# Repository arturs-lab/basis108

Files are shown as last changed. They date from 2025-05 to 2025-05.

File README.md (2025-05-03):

# basis108
Document my computer Basis 108 and its components. Organize various bits of documentation from 3rd parties that I've found across the web.

It is not my intent to violate any rights of Copyright/Trade Mark owners here. If any lawful rights owner finds content here which they do not wish included here, please contact me and I will promptly remove such content.

# History
I bought my Basis 108 in Netherlands around 1990. It appears to be a kit or early version of this computer as compared to production version that I've found traces of out on the internet. My copy came enclosed in home made case made of stainless steel with main board mounted on wooden straps glued to it. Floppy drives were mounted using metal straps resembling those found in kid's construction kits. main boards itself has no silkscreen but appears to have been produced and assembled in factory. A separate keyboard was included which was controlled by its own processor and sent keystrokes to the computer over a parallel flat ribbon cable. Sadly, this keyboard was lost.

# Platform
This computer appears to be a clone of Apple ][ with Z80 processor integrated into the main board. This allowed it to not only run Apple DOS but also CP/M. I have disks with CP/M 2.2 and 3.0. I spent most of my time in the latter writing programs in Turbo Pascal 3.0 and Z80 assembly. Besides the main board and floppy drives, the machine came with a built in power supply delivering +12, +5, -5 and -12V. I no longer have this power supply and use PC power supply instead. It also came with a Floppy Drive Controller. This controller appears to have two connectors for a typical Apple format Floppy drives. It also has some additional circuitry and what appears to be a Shugart style interface which is connected to two Teac FD-55F-03-U drives. These drives appear to have been modified to allow 80 or 40 track operation controlled by a switch mounted on front panel of computer.

# Please help!
If anyone out there has more information about this computer, please reach out to me and share what you have so that I may 8nclude it in this archive.

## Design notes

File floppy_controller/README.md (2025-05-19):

This appears to be a version of Ehring FDC4 controller.

The Ehring FDC4 is described here
https://www.applefritter.com/appleii-box/H085_AppleIIFDC4.htm

# Controller modifications

Originally the only modification was that switch 1 on switch block was turned on, and two wires wewre soldered across it which go to a switch mounted on front panel. This allows switching both drives between 80 and 40 track mode by double-stepping track motor in 40 track mode.

Second modification was adding two pullup resistors pulling up unused INDEX and DRIVE CHANGE lines. Both these signals come our of floppy drives through open collector output which means that no signal will show on them without a pullup. This comes in handy when monitoring the system with oscilloscope and has no other affect since these lines are otherwise unused.
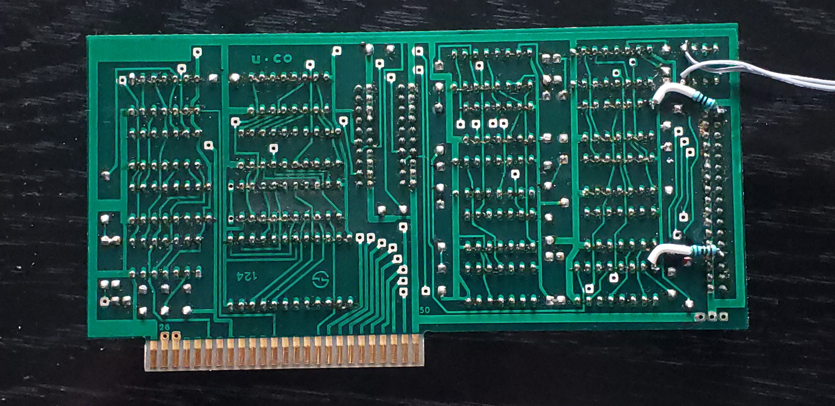
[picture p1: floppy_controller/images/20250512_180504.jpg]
Both mods seen here


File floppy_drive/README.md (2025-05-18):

The black/white wire soldered to where R14 used to be as seen here
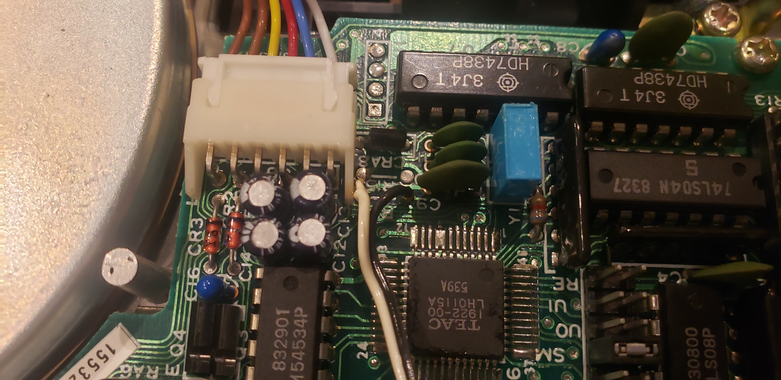
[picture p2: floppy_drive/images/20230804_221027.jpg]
bw cable

goes to a switch with that resistor soldered to it.
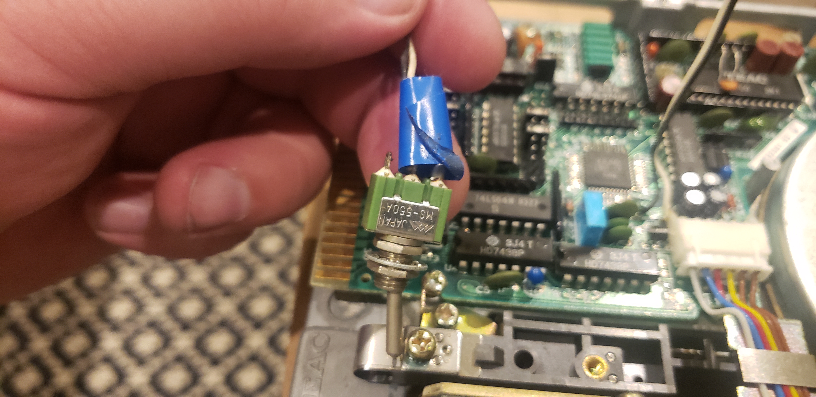
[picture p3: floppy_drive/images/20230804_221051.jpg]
switch

This allows switching the drive between 80 and 40 track mode.

Both drives have this modification on them. There also is a switch connected to floppy drive controller which switches both drives between single-sided and double-sided modes.

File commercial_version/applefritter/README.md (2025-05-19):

This is some information found at applefritter bulletin board talking about clone of Basis 108, which itself is a clone of Apple ][.

Since Bulletin Boards come and go, I've saved the content of this post to Basis 108 Clone _ Applefritter.htm

* https://www.applefritter.com/content/basis-108-clone
* https://archive.org/details/basis108SurvivalPack
* http://s180250204.onlinehome.us/Basis/Basis-108-EPROMs.zip
* http://oldcomputer.info/keep/c/museum/8bit/Basis_108

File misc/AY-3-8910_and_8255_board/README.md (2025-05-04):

Board that I built. It interfaces AY-3-8910 PSG and Intel 8255 PIO chip to Basis108. I also added some other experimental circuitry like IDE interface.

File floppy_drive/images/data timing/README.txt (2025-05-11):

I could not capture any pulses on READY or INDEX lines. The drive does have an index sensor but apparently it's been disabled.

On DATA line, 3 types of pulses during data transfer:
all pulses 1us wide
4us apart
7.5us apart
11.5us apart - this may be some sort of separator

Index pulses are present on index photodiode, but not on pin 8 of cable which is constantly low. They do appear on pin 8 once it gets pulled up to 5V through a 1K resistor. This suggests that the controller does not use index pulses.

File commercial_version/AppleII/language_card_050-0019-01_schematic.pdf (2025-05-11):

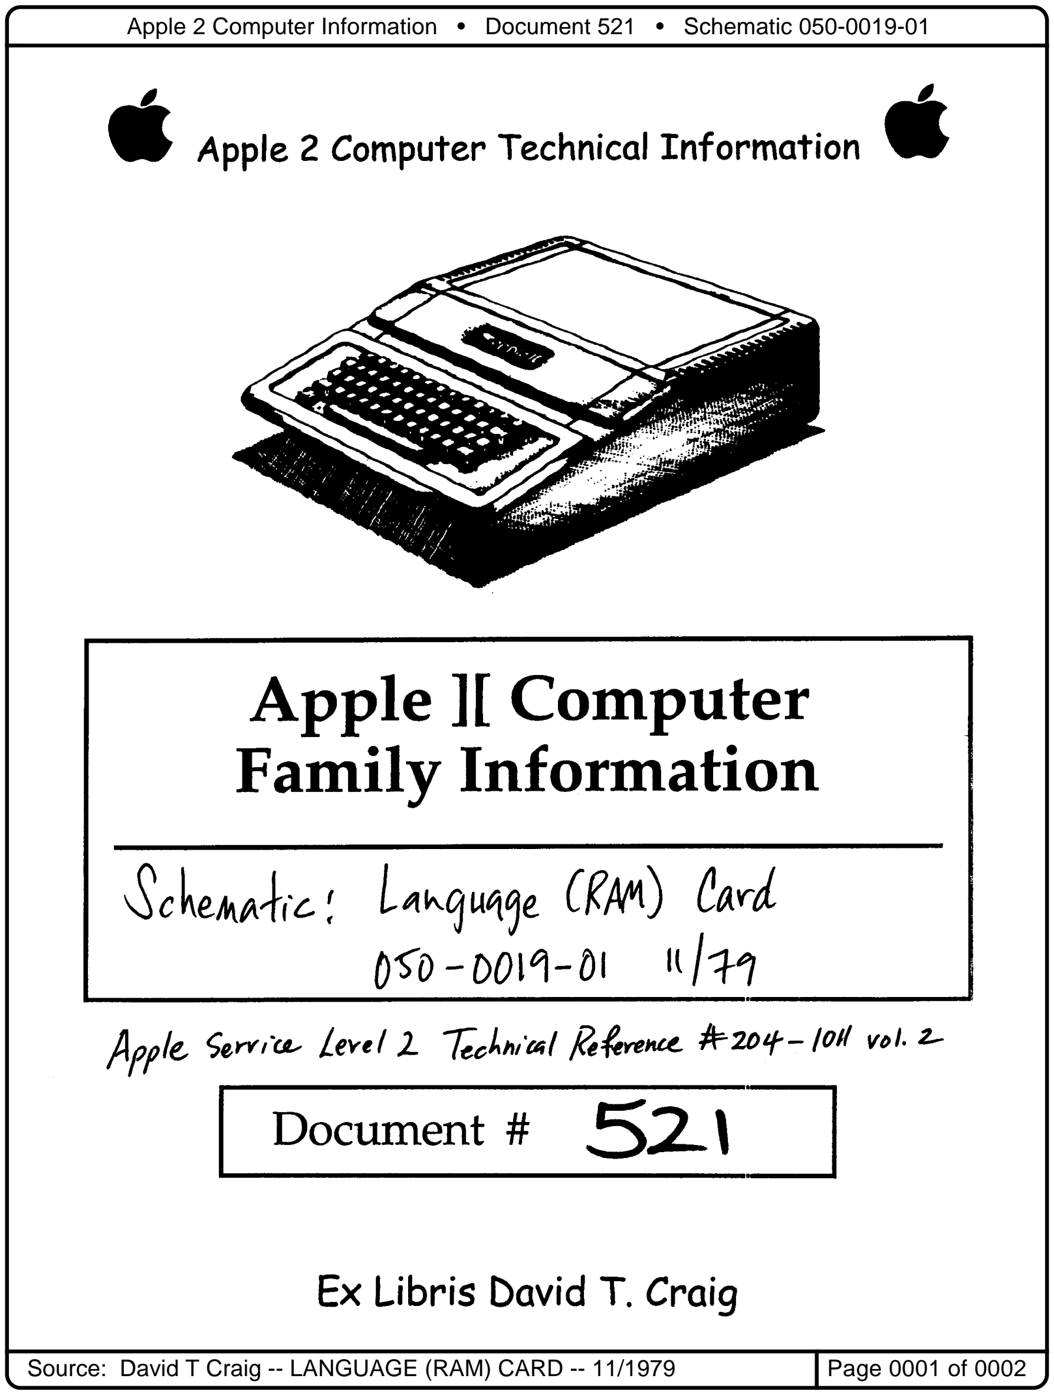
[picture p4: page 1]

Apple 2 Computer Information • Document 521 • Schematic 050-0019-01

Source: David T Craig -- LANGUAGE (RAM) CARD -- 11/1979 | Page 0001 of 0002

Apple 2 Computer Information • Document 521 • Schematic 050-0019-01

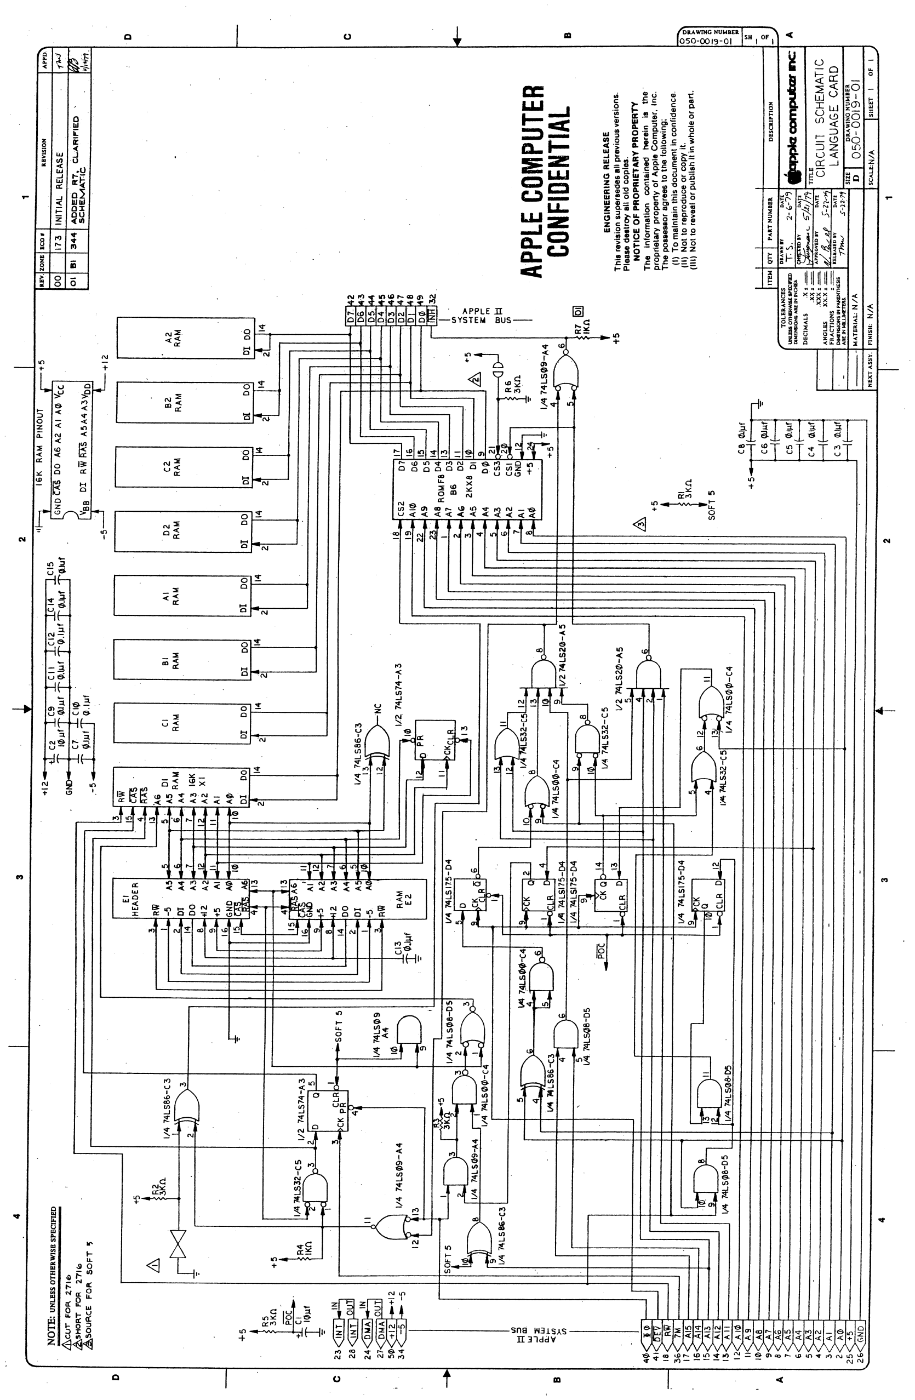
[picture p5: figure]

Source: David T Craig -- LANGUAGE (RAM) CARD -- 11/1979 | Page 0002 of 0002

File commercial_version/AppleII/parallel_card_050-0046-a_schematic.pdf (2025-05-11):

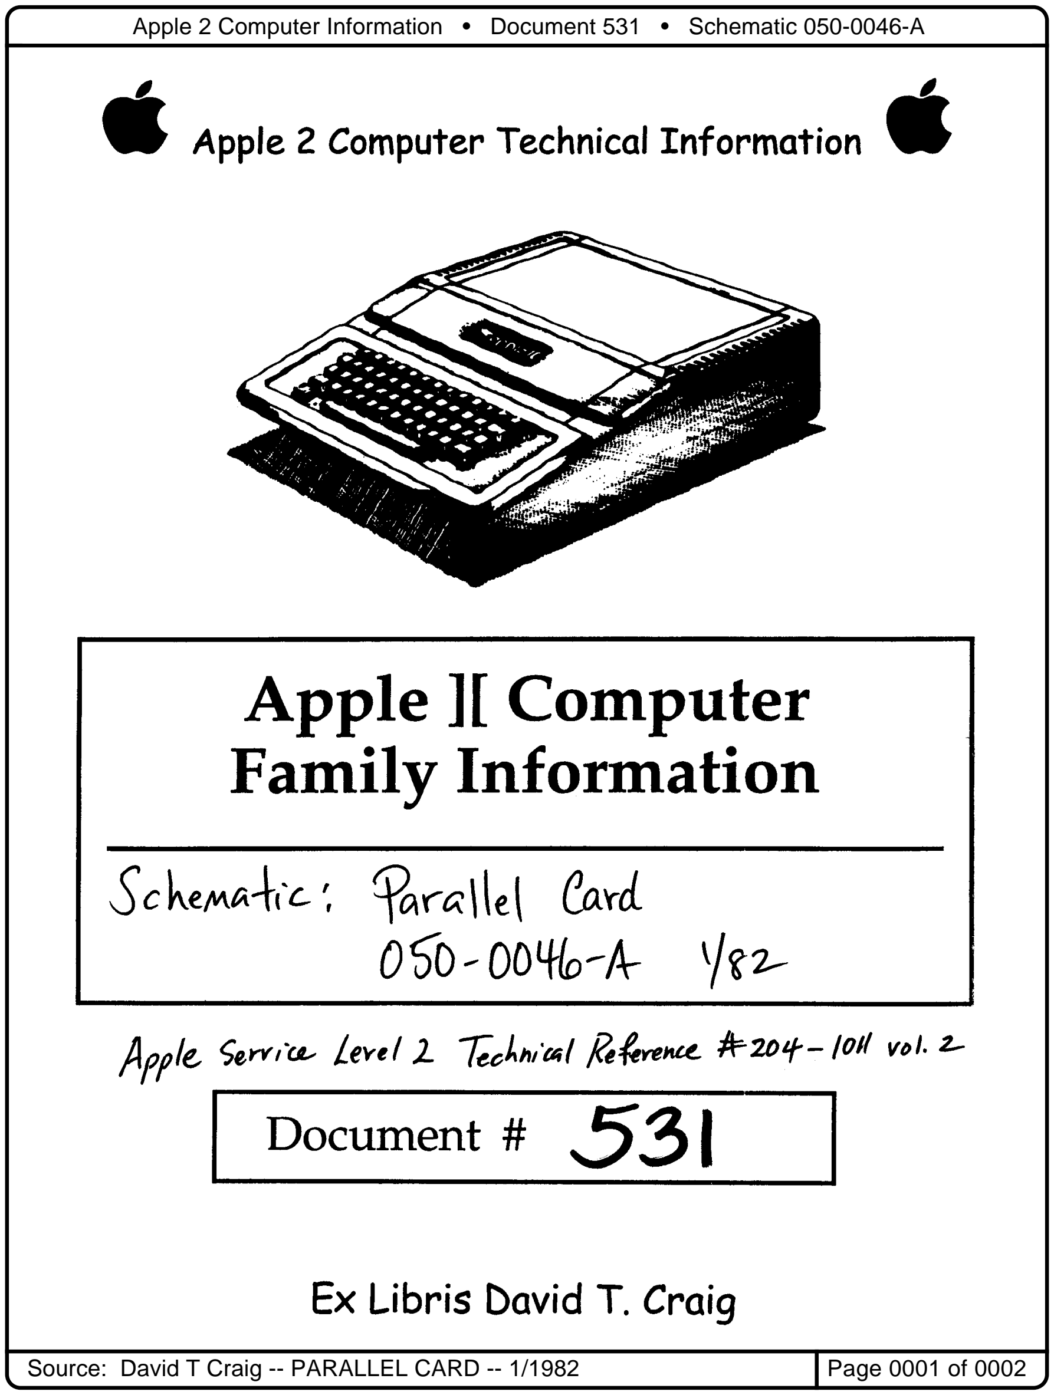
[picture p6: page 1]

Apple 2 Computer Information • Document 531 • Schematic 050-0046-A

Source: David T Craig -- PARALLEL CARD -- 1/1982 | Page 0001 of 0002

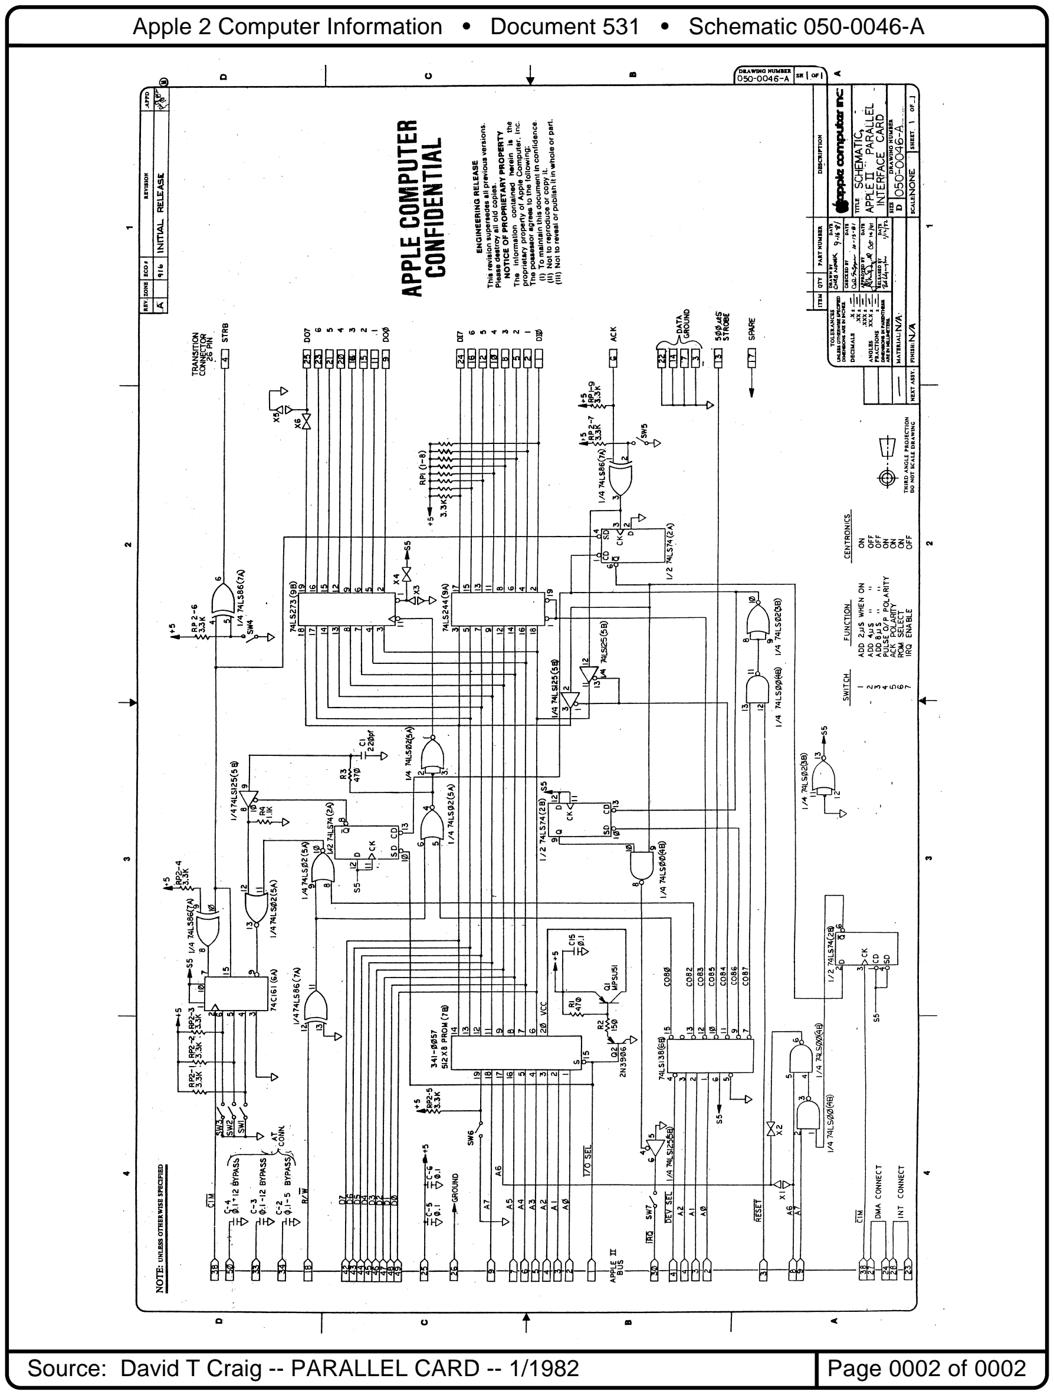
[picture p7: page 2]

Apple 2 Computer Information • Document 531 • Schematic 050-0046-A

Source: David T Craig -- PARALLEL CARD -- 1/1982 | Page 0002 of 0002

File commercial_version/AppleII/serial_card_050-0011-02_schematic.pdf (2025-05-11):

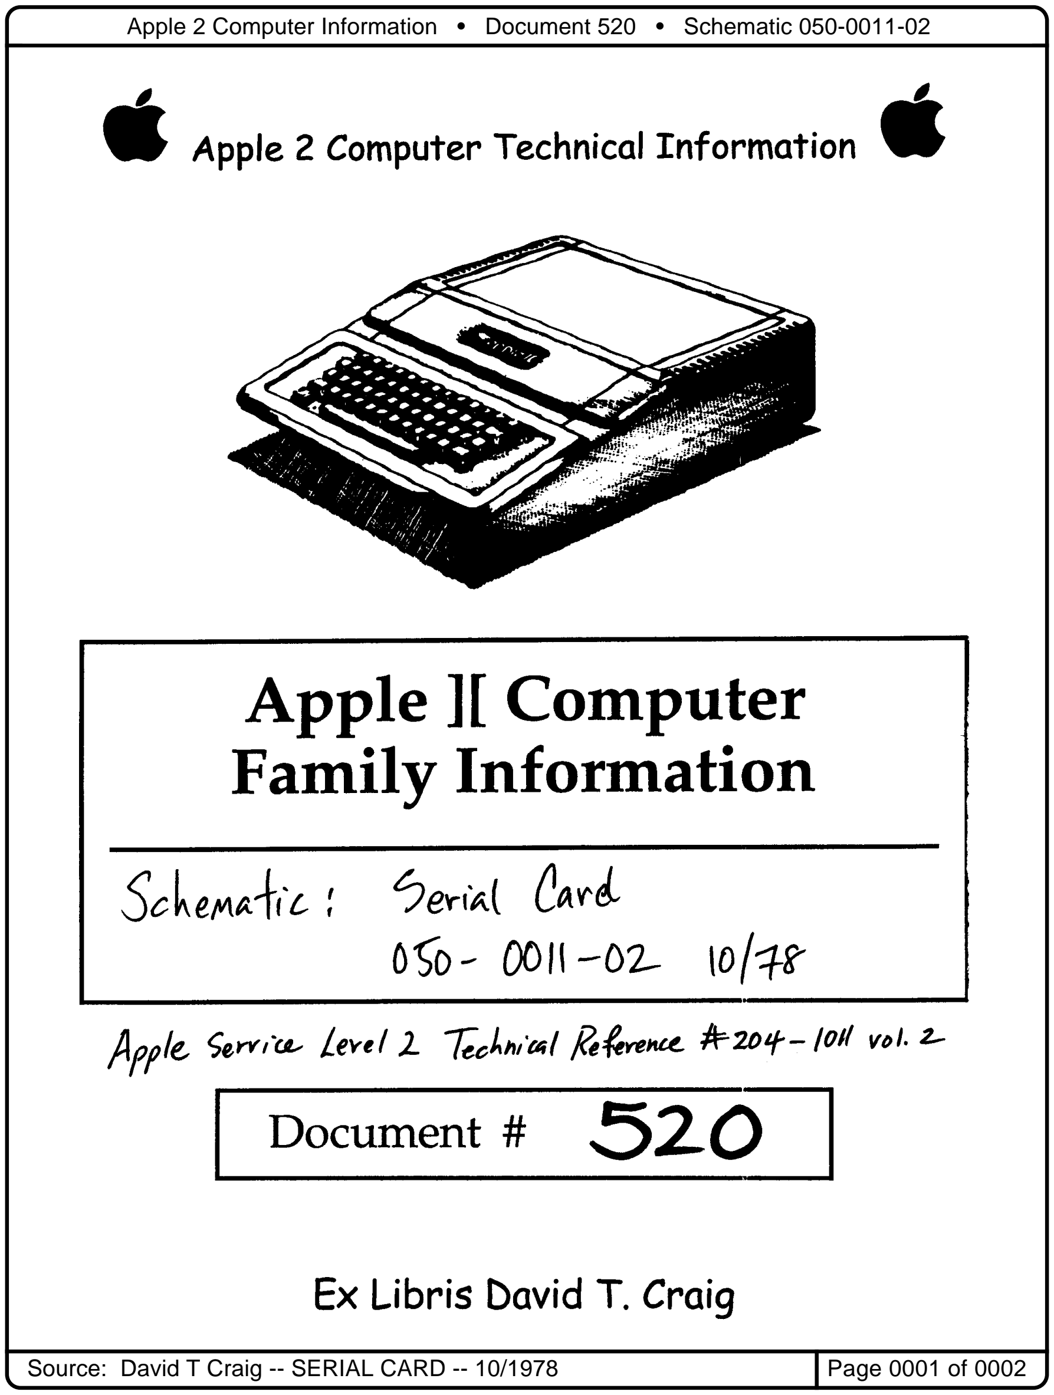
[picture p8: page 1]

Apple 2 Computer Information • Document 520 • Schematic 050-0011-02

Source: David T Craig -- SERIAL CARD -- 10/1978 | Page 0001 of 0002

Apple 2 Computer Information • Document 520 • Schematic 050-0011-02

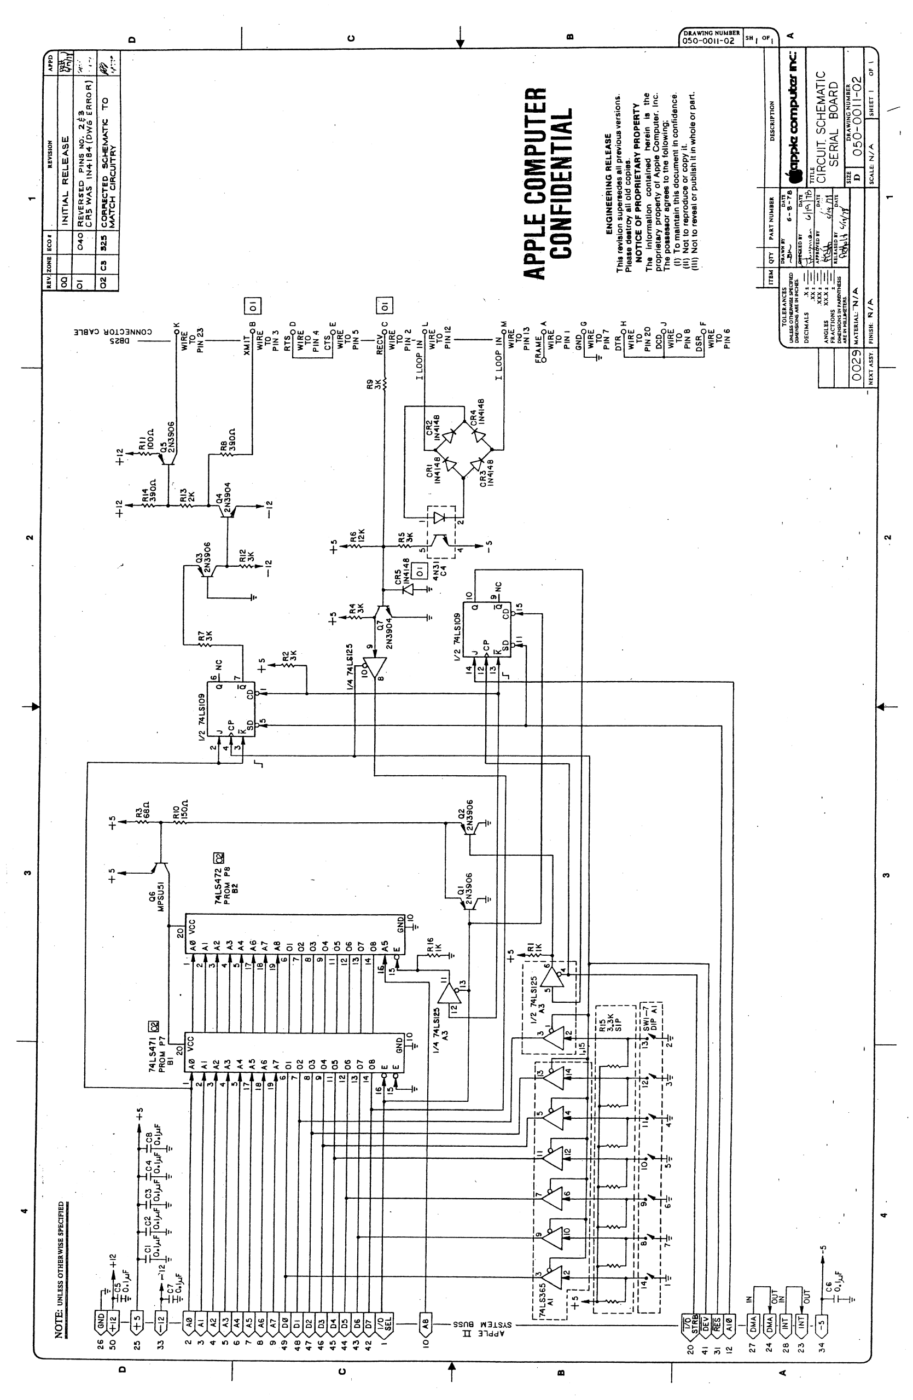
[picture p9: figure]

Source: David T Craig -- SERIAL CARD -- 10/1978 | Page 0002 of 0002

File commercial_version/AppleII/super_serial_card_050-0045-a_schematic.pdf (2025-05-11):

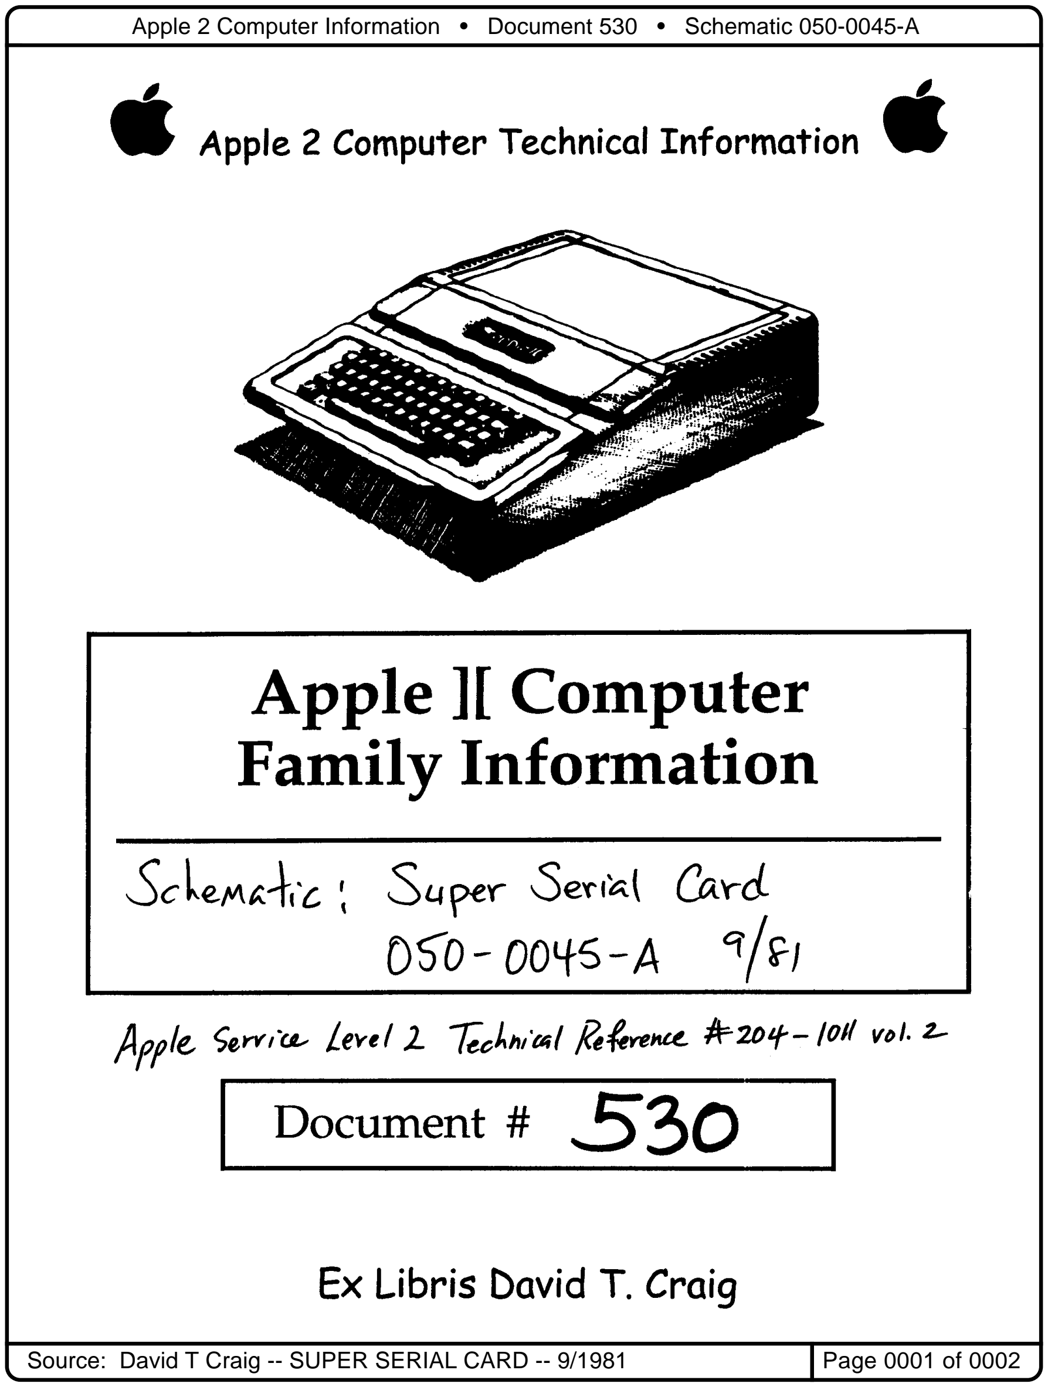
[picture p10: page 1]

Apple 2 Computer Information • Document 530 • Schematic 050-0045-A

Source: David T Craig -- SUPER SERIAL CARD -- 9/1981 | Page 0001 of 0002

Apple 2 Computer Information • Document 530 • Schematic 050-0045-A

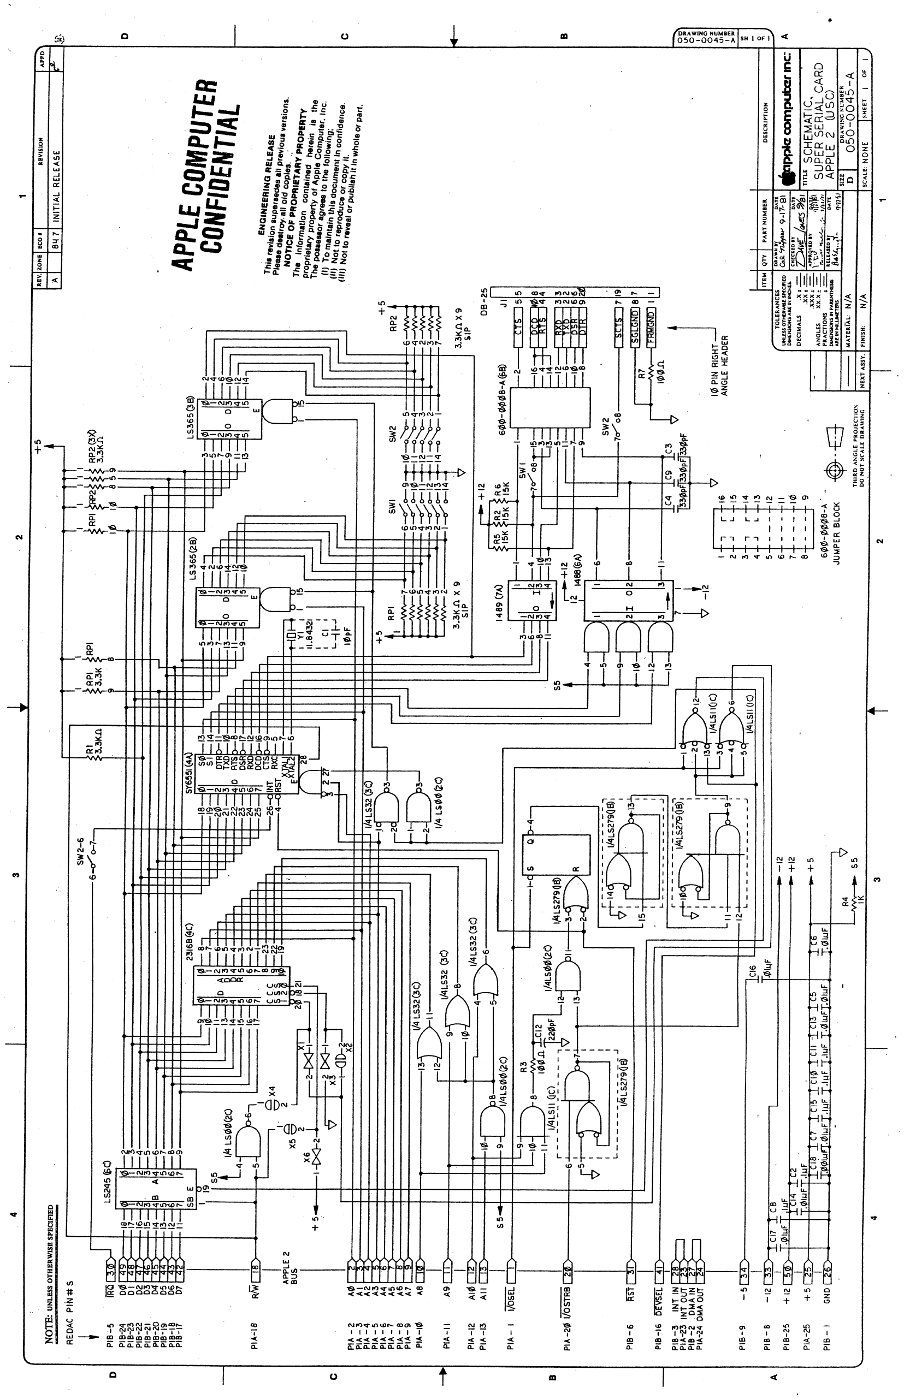
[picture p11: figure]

Source: David T Craig -- SUPER SERIAL CARD -- 9/1981 | Page 0002 of 0002

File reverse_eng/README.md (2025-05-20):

# Disassembly of code
Reverse engineering code from Basis 108 ROMs and CPM floppies to understand CPM boot process

Boot sectors from CP/M disk tracks 0 - 2 get loaded into memory starting at $800, then code gets executed starting from $801

# Data corruption analysis

I shared my thoughts on possible EPROM data corruption in my comments in README.md file in main_board/rom directory.

Focusing on d5 chip:
As seen in MD5 checksums, images of d5 EPROM differ across the three copies available
```
bcaa84a76a547e1f8acba9525073f068  d5.bin
cfe2c4aa8eed8fe9955d166b73957061  d5_label_2024.bin
45e97c54fc85d5095fced5f40a284ec6  d5_label_2025.bin
```
* The values that differ between the three copies are the smallest in d5.bin and bigger
 in one or both the other two copies which are more recent. This is true for both halves of EPROMs.
* The value in "middle" d5_label_2024.bin sometimes equals to that in d5.bin, sometimes
 to d5_label_2025.bin. But values in more recent file are never smaller than in an older file.
* Initially I thught that the content of two halves of d5 EPROM contain two different
 versions of the code. However both halves showing the same kind of differences as described
 above leads me to believe that the code is the same, it just aged differently.

To try to restore this chip to original values I did the following:
* I created a script make_single_byte_hex.bash which splits each available file in two halves and generates a file with one hex value per line.
* Then I wrote a python script which takes various combinations of these files and compares values in them. This allowed me to observe that values in the files only grow with time, never shrank.
* Using the same python file I can compare the two halves of the oldest file I have and use the smaller value of the two in the output. This hopefully restores the correct value for the given location. Unless they both got corrupted differently and neither is correct.
* This script also can output data in Intel hex format which will fill one half of 2764 EPROM. I saved this output to file d5_restore.hex. I then used Xgecu software to load this file twice to fill entire chip and output resulting file as d5_restore_x2.hex.
Sadly none of this work was of much use. I ended up with a, EPROM which didn't work. Meanwhile the original EPROM with all of its discrepancies, when put back in machine - works fine. Perhaps all the past readings of it are incorrect. Still, I'm documenting all this work in case it becomes handy in the future.

What puzzles me is that the machine seems to still be operating correctly despite this seemingly deep corruption. Either the EPROM is fine or I'm not hitting the locations that are corrupted or the corruption is not enough to result in crash. Although it may be enough to lead to data corruption on disks for example. I wonder if corruption only affects the EPROM memory locations that are never accessed because I'm not using this part of code. And the locations that are accessed get sort of "refreshed" enough to keep them alive.

## Notes
* 6502 reset/NMI vectors
```
$fffa	faaa	; NMI
$fffc	fa62	; reset
$fffe	fa40	; IRQ/BRK
```
## manual page 56
```
3f0,3f1	BRK handler vector
3f2,3f2	warm start vector ( monitor Q uses this vector)
3f3		einshalt byte
3f5,6,7	jump command for fpbasic subroutine. normally 4c 58 ff
3f8,9,a	jump command for USER (U) call
3fb,c,d	jump to NMI handler
3fe,3ff	INT handler vector
4f9	     0=40 char !=0 = 80 char
```
## memory banks page 58

| Bank 0 active | Bank 1 active | Adress space |
|---|---|---|
|  $C060w |  $C061w |  $0000 $1FFF |
|  $C062w |  $C063w |  $2000 $3FFF |
|  $C064w |  $C065w |  $4000 $5FFF |
|  $C066w |  $C067w |  $6000 $7FFF |
|  $C068w |  $C069w |  $8000 S9FFF |
|  $C06Aw |  $C06Bw |  $A000 $BFFF |
|  $C06Cw |  $C06Dw |  $D000 $DFFF |
|  $CO6Ew |  $CO6Fw |  $E000 $FFFF |

## The static RAM for the 80 column display
```
$C00Dw Additional RAM switched on, normal RAM switched off
$C00Cw Additional RAM switched off, Normal RAM switched on
```
## io ports page 97

## z80 part page 99
### Controlling the Z-80 Section
The Z-80 section is controlled by write commands to the memory space, which normally contains
peripheral ROMs. It is very important to work with write commands to ensure that the 6502 
does not perform two accesses in a row (this would prevent switching back to the 6502).
When the BASIS 108 is turned on, the (RESET) signal turns off the Z-80 section.
The (RESET) signal is synchronized with the internal clock to ensure that a write operation 
cannot be interrupted. The Z-80 immediately enters a wait mode and remains there until 
the Z-80 section is activated.

After receiving a write command in the correct memory area, the Z-80 section is turned on. 
The Z-80 remains in a wait mode until a memory clock with address information for the 
Z-80 section appears. The Z-80 is now released from wait mode and runs without further wait cycles.
Upon receipt of another write command in the same memory area (this time from the Z-80 itself), 
the Z-80 is shut down. The memory addresses for controlling the Z-80 are:
`$C100 - $C1FF`

## Mapping of Z80 address space to 6502 address space
| Z-80 Adresses	| 6502 Adresses |
|---|---|
|  $0000-$0FFF  |  $1000-$1FFF  |
|  $1000-$1FFF  |  $2000-$2FFF  |
| ... |
|  $A000-$AFFF  |  $B000-$BFFF  |
|  $B000-$BFFF  |  $D000-$DFFF  |
|  $C000-$CFFF  |  $E000-$EFFF  |
|  $D000-$DFFF  |  $F000-$FFFF  |
|  $E000-$EFFF  |  $C000-$CFFF  |
|  $F000-$FFFF  |  $0000-$0FFF  |

## Summary of Input/Output Addresses
| Address | Read | Write |
|---|---|---|
| $C000 | Keyboard | Inverse |
| $C001 |  | Flash | 
| $C002 |  | SW1 off | 
| $C003 |  | SW1 on | 
| $C004 |  | SW2 off | 
| $C005 |  | SW2 on | 
| $C006 |  | 2 x 128 characters | 
| $C007 |  | 2 x 64 + 128 characters | 
| $C008 | Keyboard Extensions | Keyboard interrupt off | 
| $C009 |  | Keyboard interrupt on | 
| $C00A |  | 40 characters/line | 
| $C00B |  | 80 characters/line | 
| $C00C |  | Static RAM off | 
| $C00D |  | Static RAM on | 
| $C00E |  | $C08x active | 
| $C00F |  | $C08x blocked | 
| $C010 | Keyboard Strobe |  | 
| $C020 | Keyboard Output |  | 
| $C030 | Speaker |  | 
| $C04x | Utility Strobe | Utility Strobe | 
| $C050 | Graphics On |  | 
| $C051 | Graphics Off |  | 
| $C032 | Graphical Display |  | 
| $C053 | Mixed Graphics |  | 
| $C054 | Page 1 Active |  | 
| $C055 | Page 2 Active |  | 
| $C056 | LO-RES Graphics |  | 
| $C057 | HI-RES graphcs |  | 
| $C058 | TTL-0 low |  | 
| $C059 | TTL-0 high |  | 
| $C05A | TTL-1 low |  | 
| $C058 | TTL-1 high |  | 
| $C05C | TTL-2 low |  | 
| $C05D | TTL-2 high |  | 
| $C05E | TTL-3 low |  | 
| $C05F | TTL-3 high |  | 
| $C060 | Cassette Input | $0000 - $1FFF Bank 0 | 
| $C061 | TTL Input 1 | $0000 - S1FFF Bank 1 | 
| $C062 | TTL Input 2 | $2000 - S3FFF Bank 0 | 
| $C063 | TTL Input 3 | $2000 - S3FFF Bank 1 | 
| $C064 | Hand Controller 0 | $4000 - S5FFF Bank 0 | 
| $C065 | Hand Controller 1 | $4000 - $5FFF Bank 1 | 
| $C066 | Hand Controller 2 | $6000 - $7FFF Bank 0 | 
| $C067 | Hand Controller 3 | $6000 - $7FFF Bank 1 | 
| $C068 |  | $8000 - $9FFF Bank 0 | 
| $C069 |  | $8000 - $9FFF Bank 1 | 
| $C06A |  | $A000 - $BFFF Bank 0 | 
| $C06B |  | $A000 - $BFFF Bank 1 | 
| $C06C |  | $D000 - $DFFF Bank 0 | 
| $C06D |  | $D000 - $DFFF Bank 1 | 
| $C06E |  | $E000 - $FFFF Bank 0 | 
| $C06F |  | $E000 - $FFFF Bank 1 | 
| $C070 | Hand Controller Strobe |  | 
| $C08x | LC Control |  | 
| $C090 |  | Printer Parallel Output | 
| $C098 | Serial Input | Serial Output | 
| $C099 | Serial Status | Serial RESET | 
| $C09A | Serial Command | Serial Command | 
| $C09B | Serial Control | Serial Control | 
| $C0Ax | Slot 2 DEVICE Select | Slot 2 DEVICE Select | 
| ... |
| $C0Fx | Slot 7 DEVICE Select | Slot 7 DEVICE Select | 
| SC100 |  | Z80 On/Off | 
| SC1C1 | Printer Acknowledge |  | 

## helpful references
[softswitches](http://apple2.guidero.us/doku.php/mg_notes/general/io_page)
[page 0](https://www.kreativekorp.com/miscpages/a2info/zeropage.shtml)and(https://fadden.com/apple2/dl/zero-page.txt)

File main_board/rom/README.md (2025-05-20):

Labels like 'd4' indicate location of the chip on Basis108 main board.

d4 - Starlight software d000-efff - this memory area is used for Basic ROM in original Apple

d5 - BASIC ROM - lower half of this EPROM is visible in Apple mode at $F000-$FFFF. There is more code in the upper half of this EPROM. It seems to be similar to the lowewr half. 
Perhaps these are two copies of the same data but they got corrupted and now look slightly different. Or similar but different code that is bank-switched. 
The two halves can be compared using something like ```diff -W 40 --side-by-side -a <(xxd -ps -c 8 d5_label_2024.bin) <(dd if=d5.bin bs=1 skip=4096 | xxd -ps -c 8) | less```
code starting at $0E00 in d5.hex is similar to that provided on page 156 of commercial version's manual /commercial_version/documents/BASIS108_300pdi.pdf.
So does code starting in second half at $1E00.
Also code on page 133 and on is similar to that at EPROM offset $0800 and $1800

g14 - printer driver According to the manual only 256 bytes of this chip is being used in address space of $C100-$C1FF (Apple addressing, $E100 in CP/M). 
But there is more code within this chip. Perhaps some trickery is done to use other parts of it to bank-switch code. 
Data visible to computer start at this location in EPROM: `0040: 00 20 62 C1 90`. Driver listed on page 169 in commercial version's manual available at /commercial_version/documents/BASIS108_300pdi.pdf matches the code starting at that location.

h4 - Character generator

c14_kbd_rom_AL.bin - translates data from keyboard to apple. 1:1 mapping so for a while I just had wires in the socket as seen in old photos. To replace them with an EEPROM, I wrote quick program outputting values to a file in a loop and repeated that several times. Since I ended up with a file only half as long as EEPROM size, I loaded that file twice in Xgecu software to fill EEPROM.

c14_kbord_orig.bin - original translation rom for c14. This one has some exceptions in mappings and only partial mappings.

fdc - floppy drive controller ROM in floppy controller directory

kbd_rom.bin - keyboard firmware pulled from original keyboard. I believe it had a 6800 CPU or something like HD6303. The commercial version appears to have used Intel 8048. Code would have to be analyzed to determine whch is more likely. I'm leaning towards 6800 because at some point I wrote disassembler for it probably hoping to reverse-engineer the keyboard. Some day...

TBP28L22.HEX - 256Bx8 PROM on FD controller. Datasheet available in /resources/datasheets. Appears to contain a state machine for floppy controller. Read first time in 2025.

Some of the MD5 sums for the bin files differ for the same file across its versions. It is possible that the EPROM chips are losing their data and getting corrupted. Or they were read incorrectly in the past using the primitive methods I had available at the time. For this reason I am keeping multiple versions of these files in case another version needs to be tried once corruption is detected.

For c14_kbd_rom_AL.bin it is expected that it differs from two other copies as this version I generated myself to mtch the wires that replaced original part

For d4 it seems that only the first file - d4.bin differs from others. Is it possible that only that first copy was correct, the the EPROM got corrupted but corruption stopped and all subsequent copies read the same across years? Maybe. Or perhaps that first read was flawed, the chip is solid and all following readings contain correct data. Time will show

For d5 is it possible that the first reading of it was correct, then the chip corrupted, the two following readings 1995/romlabel.bin and d5_label_2024.bin read the same despite being 29 years apart and then the chip got corrupted even more before last reading? Seems unlikely. More likely is that the files marked 2024 were created much closer to 1995 but their date stamps based on which they got renamed to 2024 got affected during some copy process. The saving grace is that this chip seems to have the same data saved in it which aged differently. Picking the smaller value from one half of the chip or the other might let us reconstruct the data for the most part. Why the smaller? Erased state of the EPROM is $FF. When programmed, 0s get stored wherever needed in the chip and 1s remain 1s. As chips get corrupted over time, some 0s revert to 1s. But no 1 turns into 0. Exactly the behavior seen when comparing the three versions of the chip. The oldest value is the lowest, then over time it gets bigger and perhaps bigger again. But never smaller. So a reasonable presumprion is that the smallest found value for a given location is the correct one. Or the least sorrupt.

g14 is the strangest. The first and last readings match. So do the two in-between readings. Did the chip get corrupted for the two middle readings but bounced back to health for the last reading to match original? Or was the first reading flawed like suspected for original d4.bin and the chip corrupted over time to match the first flawed reading? Seems equally unlikely.

At least h4 chip matches across the board.

Files mentioning 2025 were dumped in 2025 by pulling chips and reading them with Xgecu TL866II-Plus programmer.
Files mentioning 2024 I believe were dumped the same way as 2025. Yet, the MD5 sums for some of them differ from 2025 versions.
Files just indicating location (e.g. g14.bin) were created from original *.hex files which were created back in the 90s. The hex file was read into Xgecu software and re-saved as bin. 
Files with extension of .hex and .asc were the first dump of ROMS I have. It is possible that they were originally created by reading original EPROMs using home made EPROM interface connected to ZX Spectrum clone and later transferred to CP/M. Then transferred to PC as disk image and extracted from it. A lot could have gotten corrupted in-between.
Files in directory 1995 are, I believe, dumps of ZX Spectrum tape binary files. They contain 19 byte header in ZX Spectrum format followed by contents of EPROM.

Simple way to compare two bin files:
`diff -W 40 --side-by-side -a <(xxd -ps -c 8 d5_label_2024.bin) <(xxd -ps -c 8 d5_label_2025.bin) | less`
```
1576a94d6cb334dd126cb1c27f19e0f2  c14_kbd_rom_AL.bin
dd5eed3d100baf9d3edb9eb0ba70071f  c14_kbord_orig.bin
54eeec8ae5980d63f1eb5b0c484399d6  d4.bin
98ab68f29770cf18be918f73b6e5ad8c  d4_starlight_2024.bin
98ab68f29770cf18be918f73b6e5ad8c  d4_starlight_2025.bin
bcaa84a76a547e1f8acba9525073f068  d5.bin
cfe2c4aa8eed8fe9955d166b73957061  d5_label_2024.bin
45e97c54fc85d5095fced5f40a284ec6  d5_label_2025.bin
9691479205a352a6179de522be4298ed  g14.bin
efe58797f3d49fb3b34048ff378cb270  g14_printer_2024.bin
9691479205a352a6179de522be4298ed  g14_printer_2025.bin
81601b9abea937adbe3f89ef6c5e1553  h4.bin
81601b9abea937adbe3f89ef6c5e1553  h4_chargen_2024.bin
81601b9abea937adbe3f89ef6c5e1553  h4_chargen_2025.bin

5e2a969ad1d5575d9e169bdedf32ebbf  /floppy_controller/rom/fdc.bin
7e06c18cf58ac32b30155759817559a8  /keyboard/rom/kbd.bin

MD5 sums after stripping off first 19 bytes of file in 1995 dir:
81601b9abea937adbe3f89ef6c5e1553  1995/rom_cgen.bin
dd5eed3d100baf9d3edb9eb0ba70071f  1995/romkbd1.bin - this is keyboard mapping rom on main board
7e06c18cf58ac32b30155759817559a8  1995/romkbd.bin  - this is Keyboard firmware ROM on keyboard board itself
cfe2c4aa8eed8fe9955d166b73957061  1995/romlabel.bin
efe58797f3d49fb3b34048ff378cb270  1995/romprntr.bin
98ab68f29770cf18be918f73b6e5ad8c  1995/romstar.bin
```

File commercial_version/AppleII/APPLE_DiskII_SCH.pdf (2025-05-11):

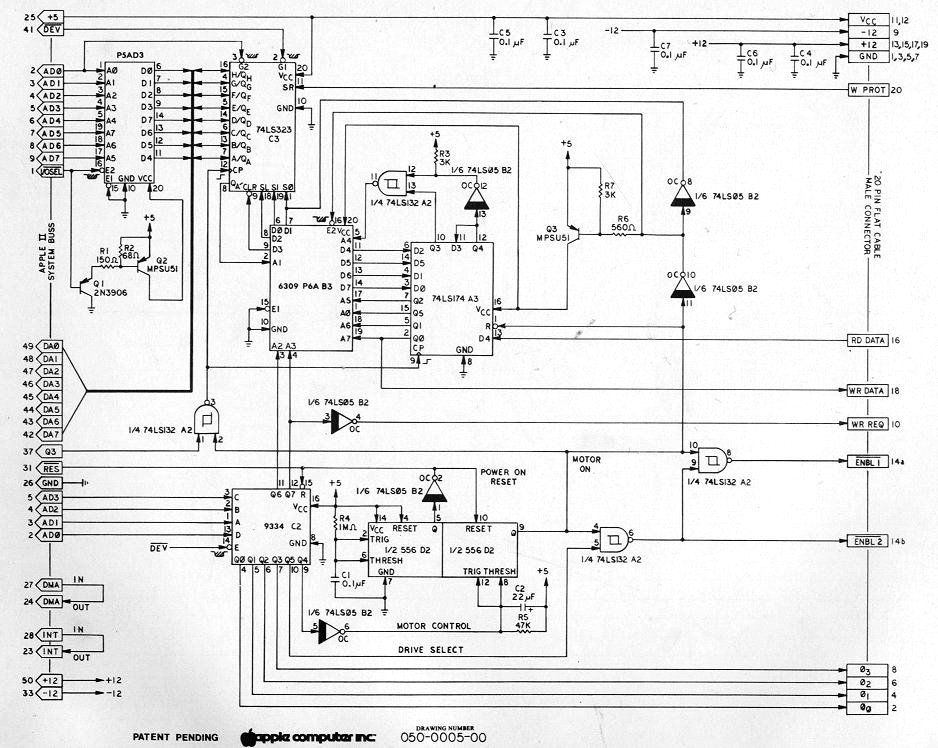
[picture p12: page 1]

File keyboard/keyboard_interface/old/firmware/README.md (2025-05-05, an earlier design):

kbd.asm seems to be the latest and most feature-full version. Including couple prior versions for reference as they might contain some different features I planned on implementing.

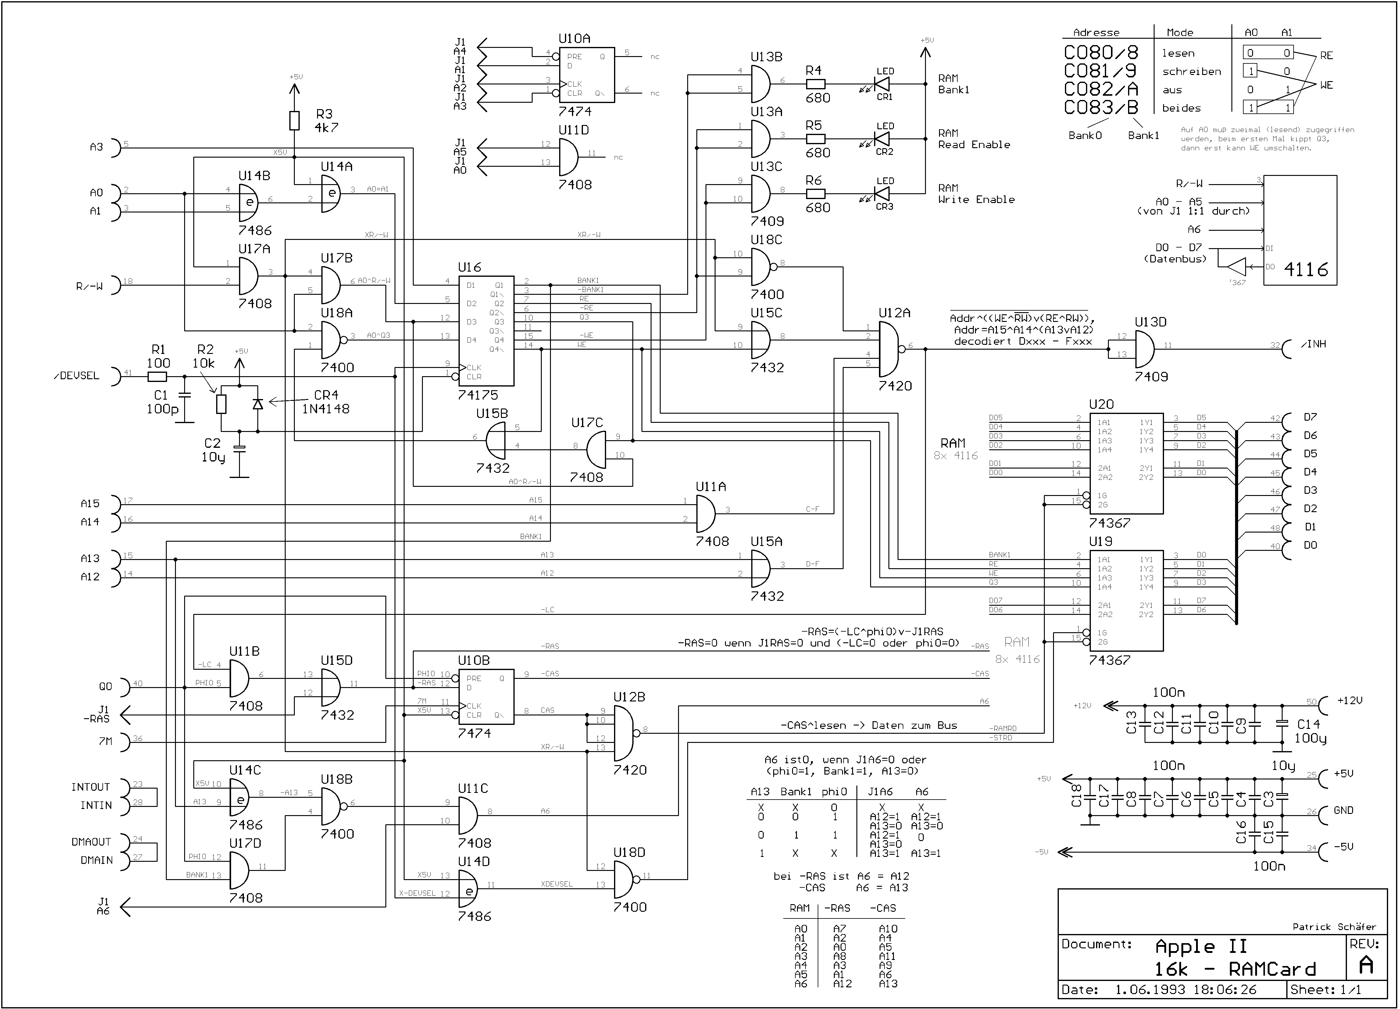
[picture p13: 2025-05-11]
commercial_version/AppleII/Apple Language Card - Schematics.gif

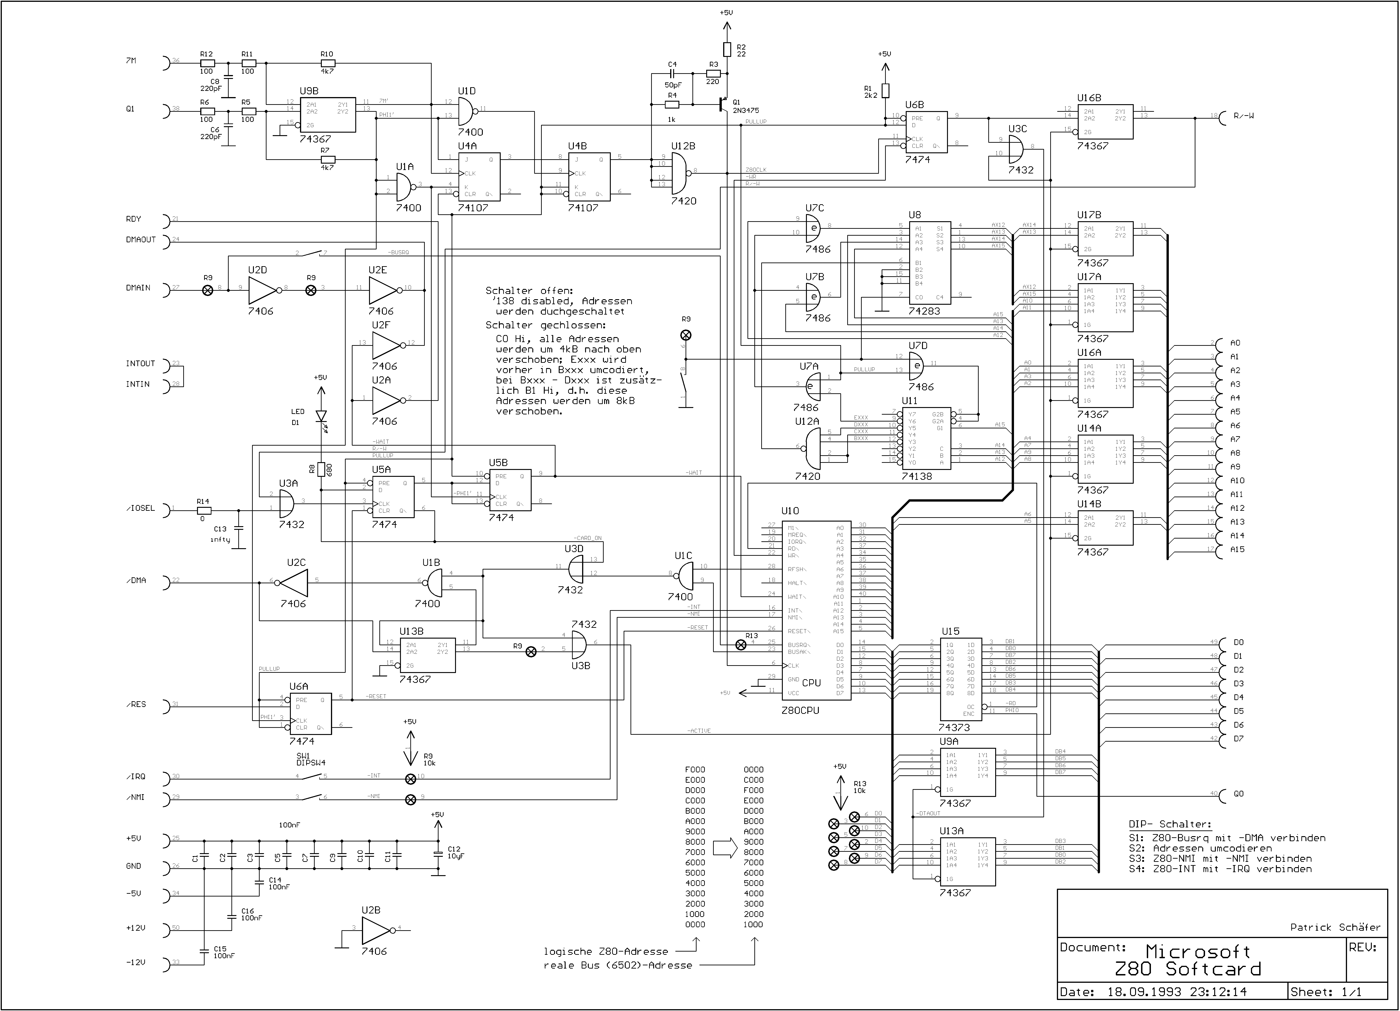
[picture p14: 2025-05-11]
commercial_version/AppleII/Microsoft Softcard - Schematics.gif

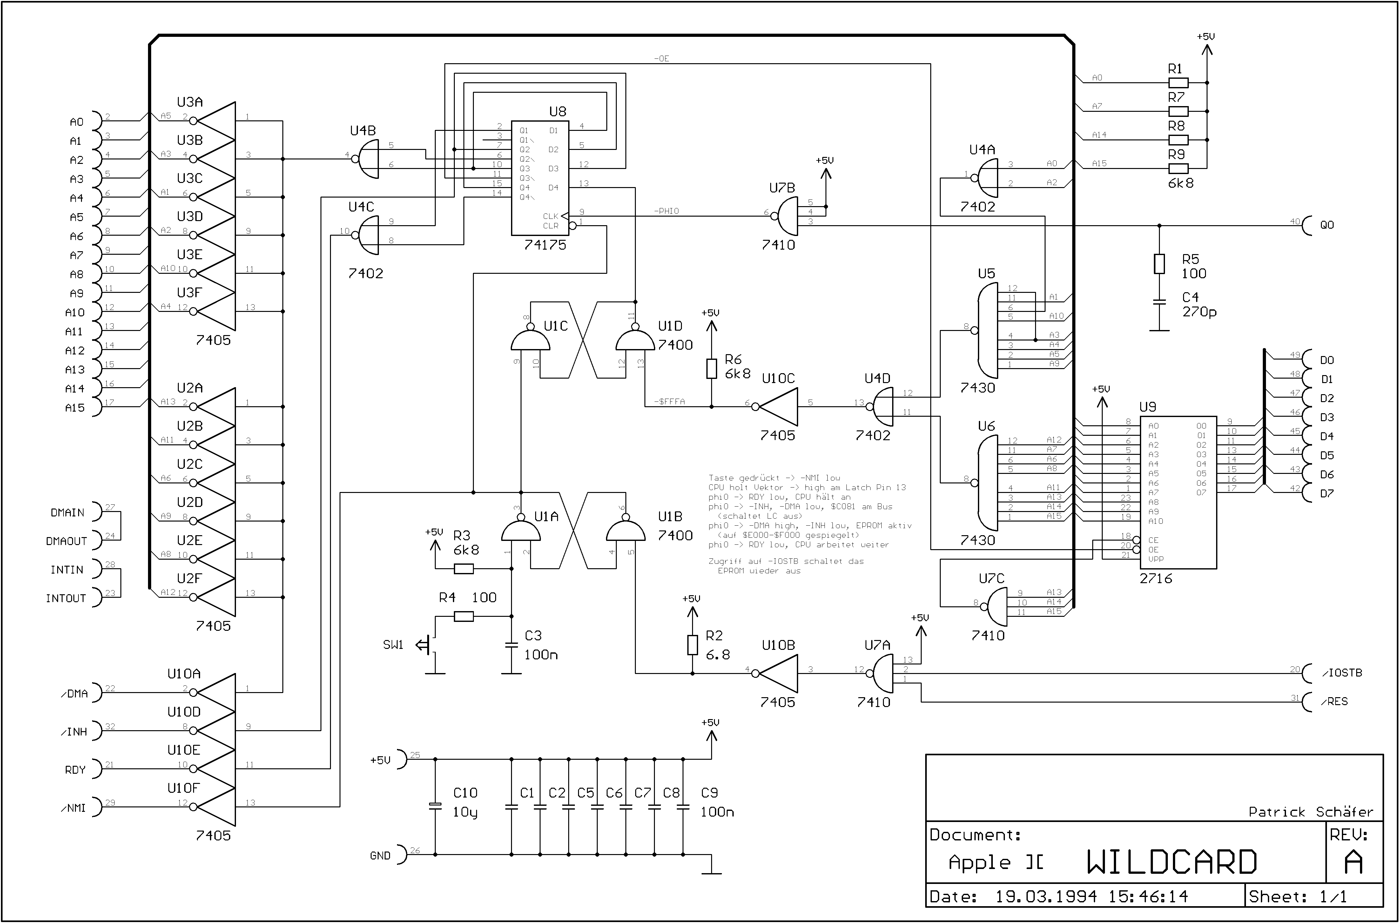
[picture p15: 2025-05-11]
commercial_version/AppleII/CPS Wildcard - Schematics.gif

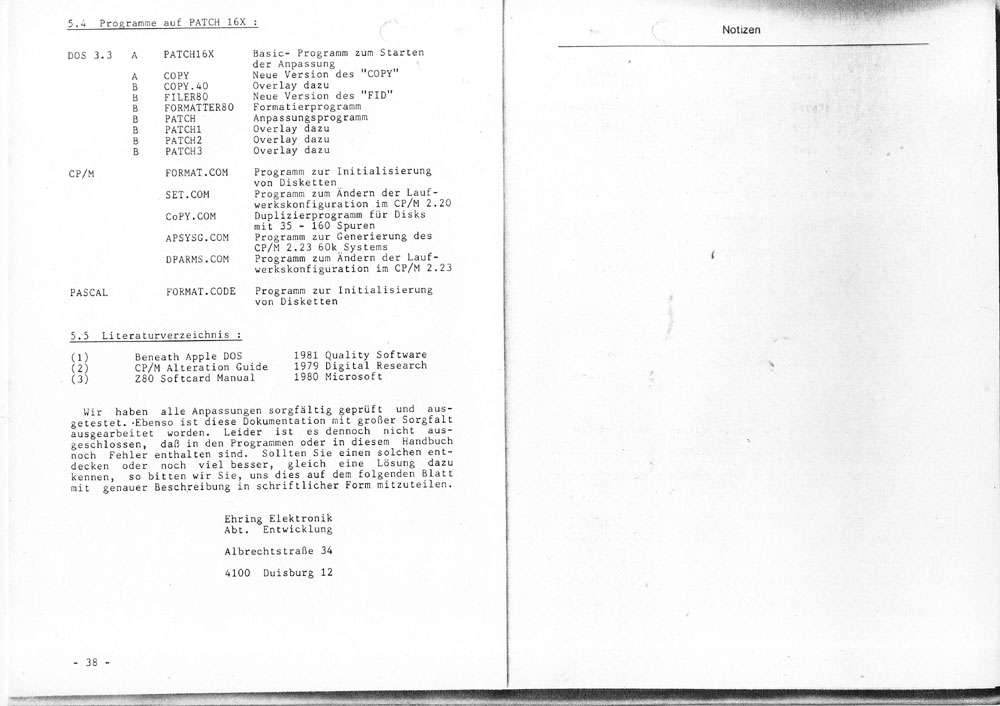
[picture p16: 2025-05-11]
floppy_controller/images/page017.jpg

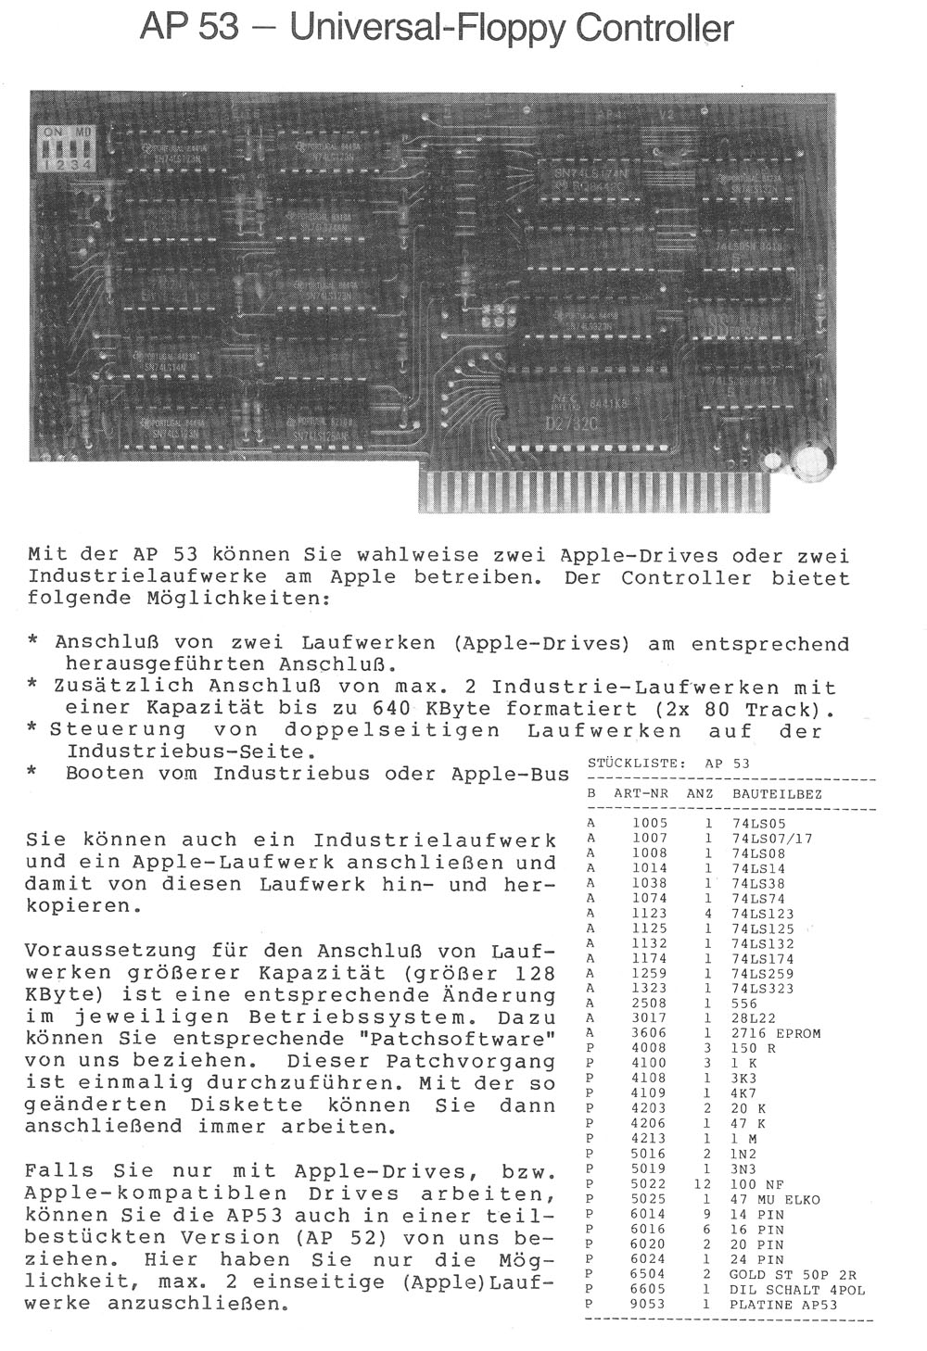
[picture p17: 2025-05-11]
floppy_controller/images/page.jpg

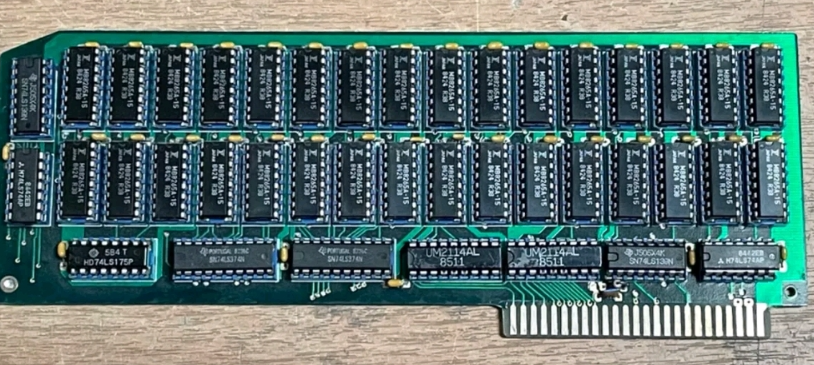
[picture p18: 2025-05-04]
commercial_version/applefritter/images/BASRAM_0.png

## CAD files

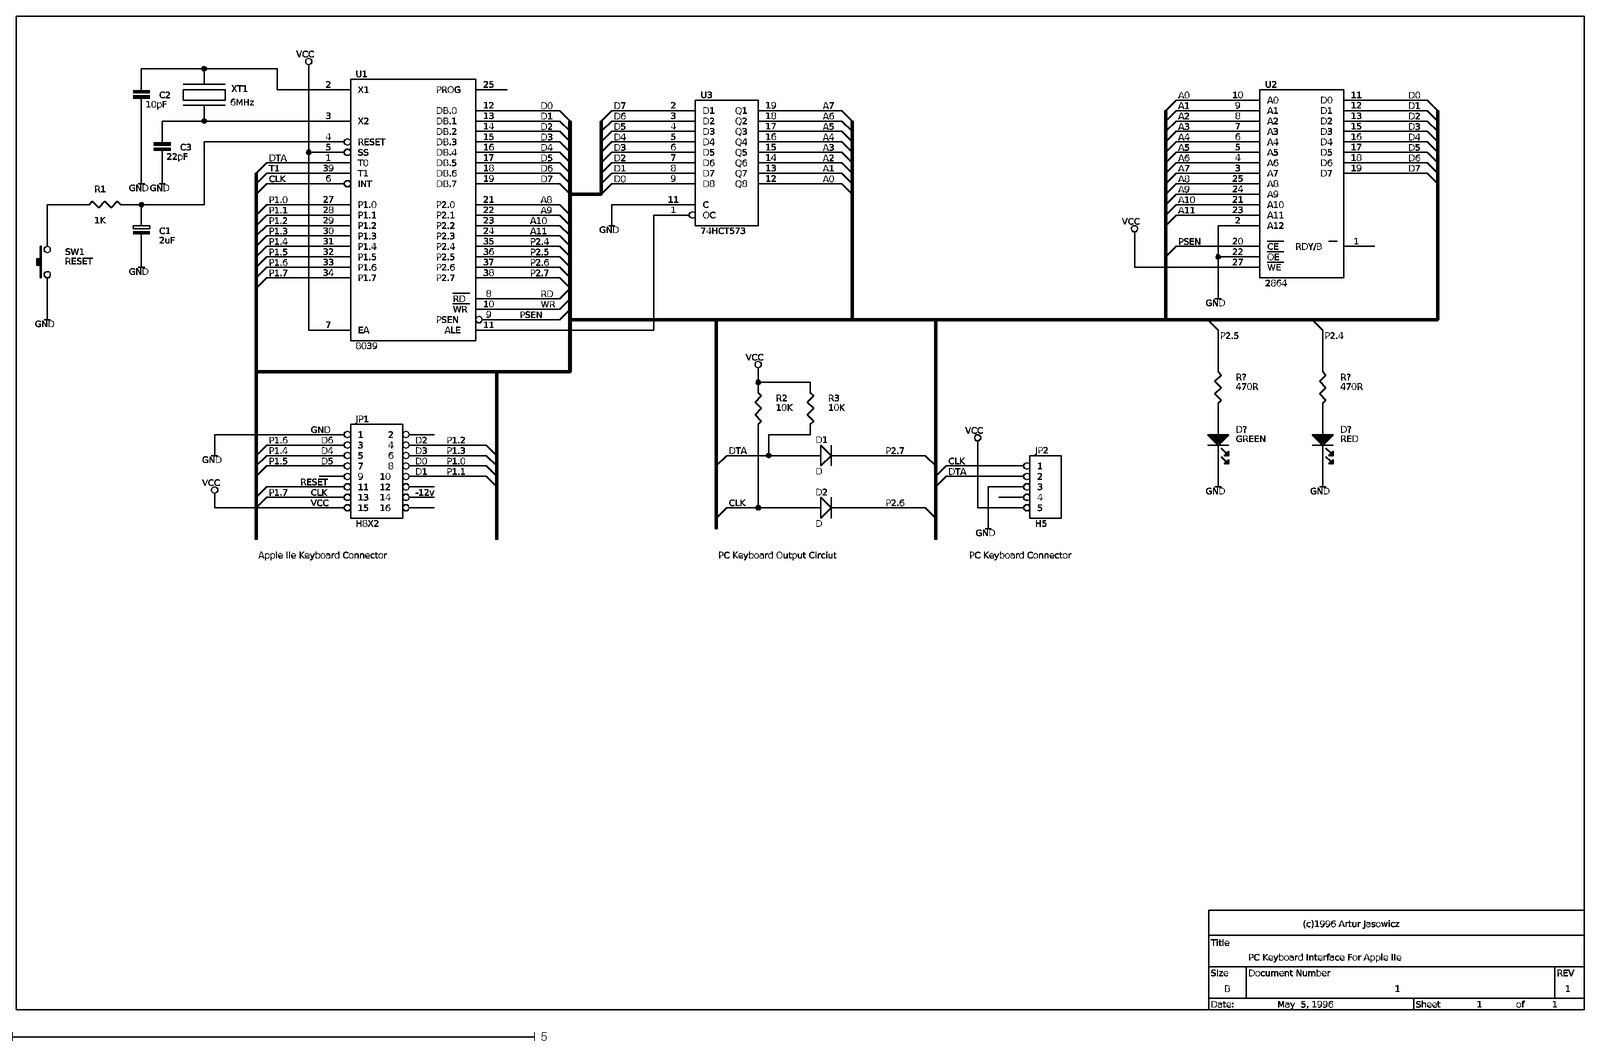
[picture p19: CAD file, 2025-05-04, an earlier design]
keyboard/keyboard_interface/old/hw/keyboard.dxf
D0
D1
D2
D3
A0
10
A1
9
A2
8
A3
7
A4
6
A5
5
A6
4
A7
3
A8
25
A9
24
A10
21
A11
23
A12
2
CE
20
OE
22
WE
27
11
12
13
15
D4
16
D5
17
D6
18
D7
19
RDY/B
1
U2
2864
Q1
Q2
Q3
Q4
Q5
Q6
14
Q7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

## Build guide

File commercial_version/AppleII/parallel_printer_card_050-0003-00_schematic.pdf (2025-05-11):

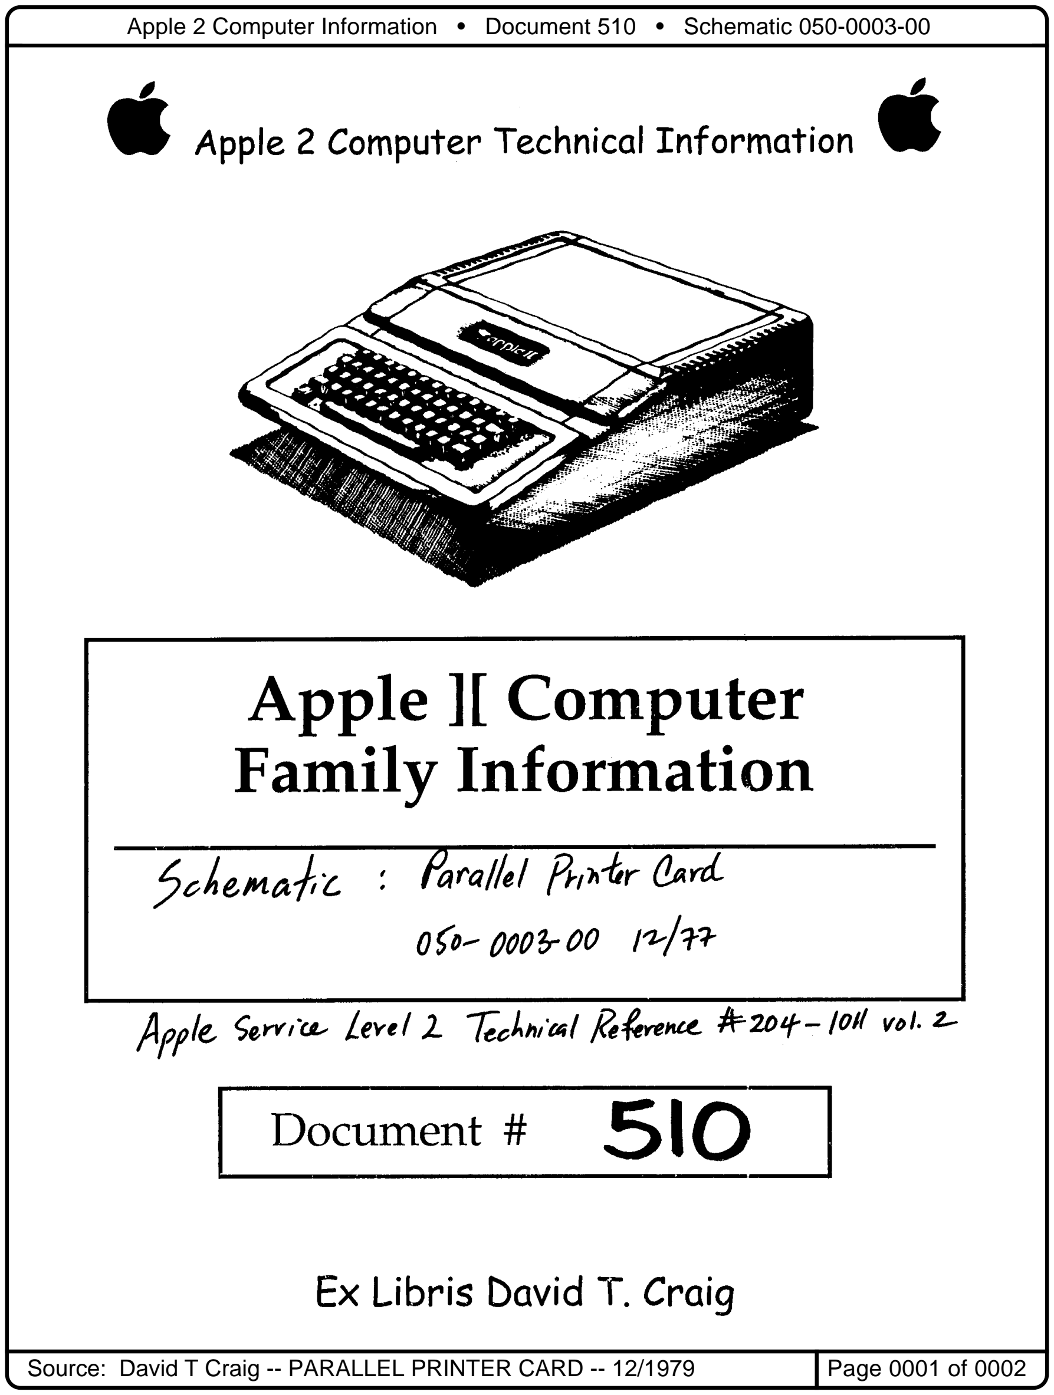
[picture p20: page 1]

Apple 2 Computer Information • Document 510 • Schematic 050-0003-00

Source: David T Craig -- PARALLEL PRINTER CARD -- 12/1979 | Page 0001 of 0002

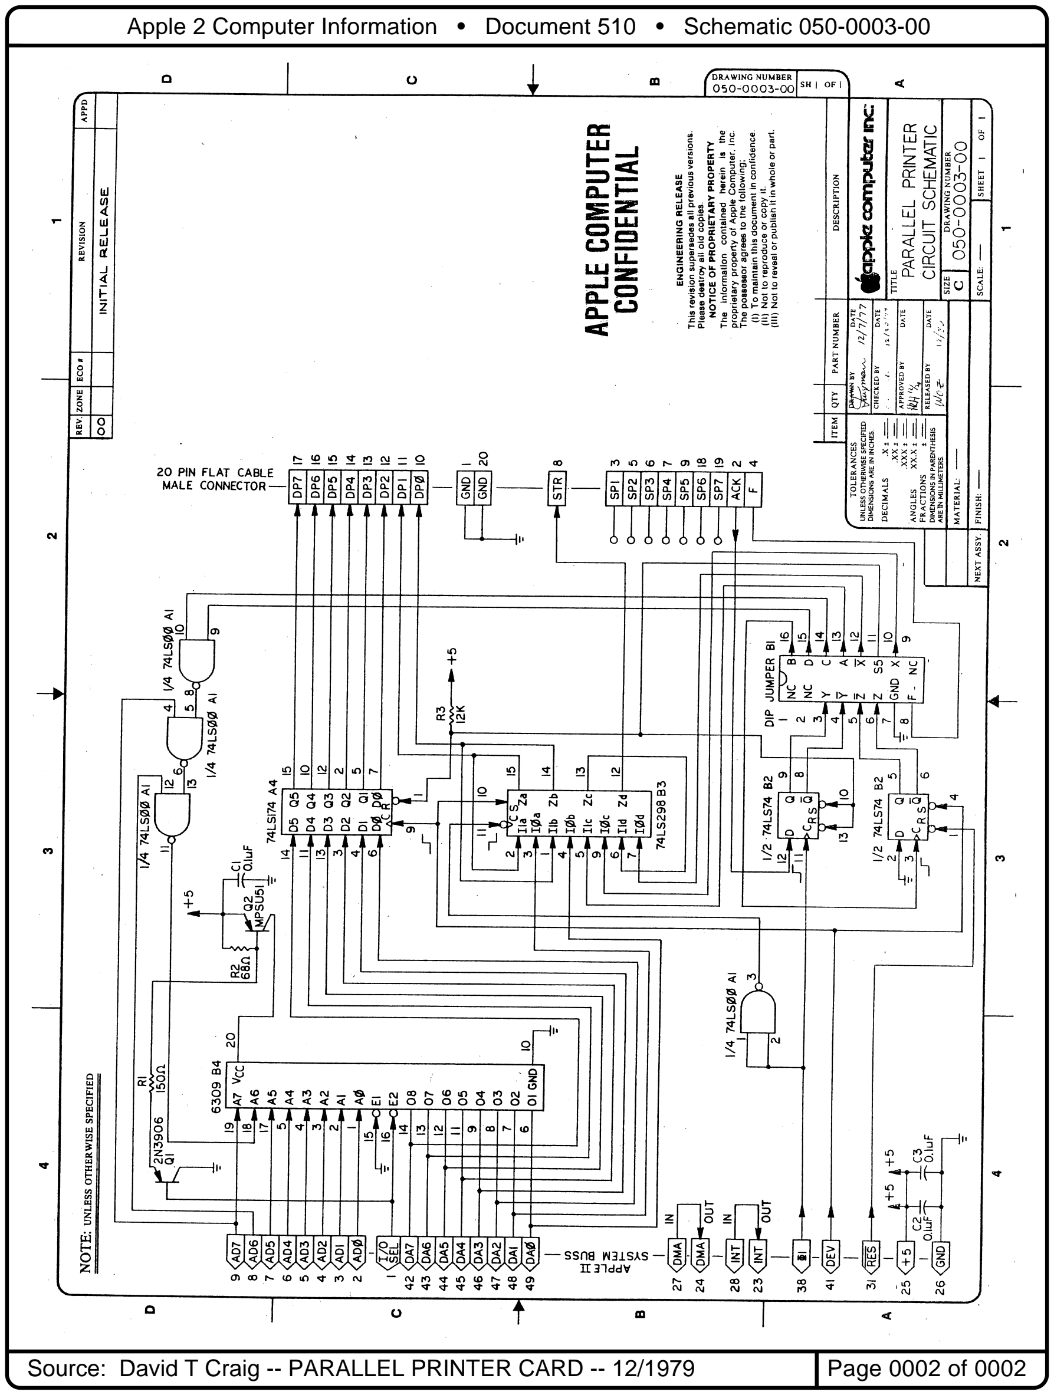
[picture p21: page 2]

Apple 2 Computer Information • Document 510 • Schematic 050-0003-00

Source: David T Craig -- PARALLEL PRINTER CARD -- 12/1979 | Page 0002 of 0002

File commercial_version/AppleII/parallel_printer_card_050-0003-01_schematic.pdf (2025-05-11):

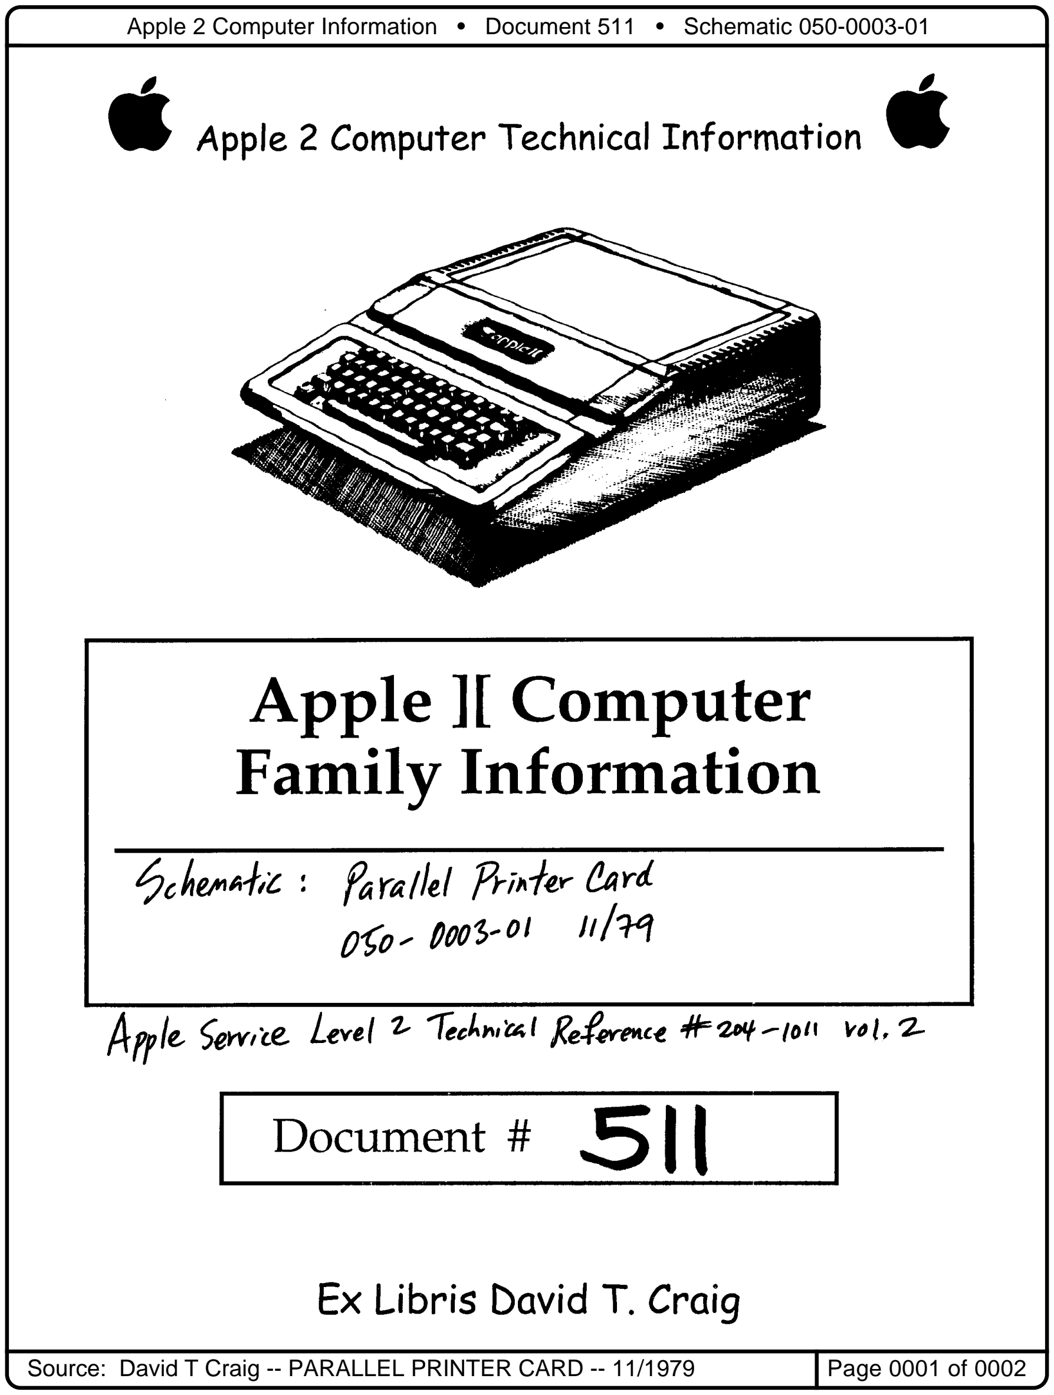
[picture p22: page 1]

Apple 2 Computer Information • Document 511 • Schematic 050-0003-01

Source: David T Craig -- PARALLEL PRINTER CARD -- 11/1979 | Page 0001 of 0002

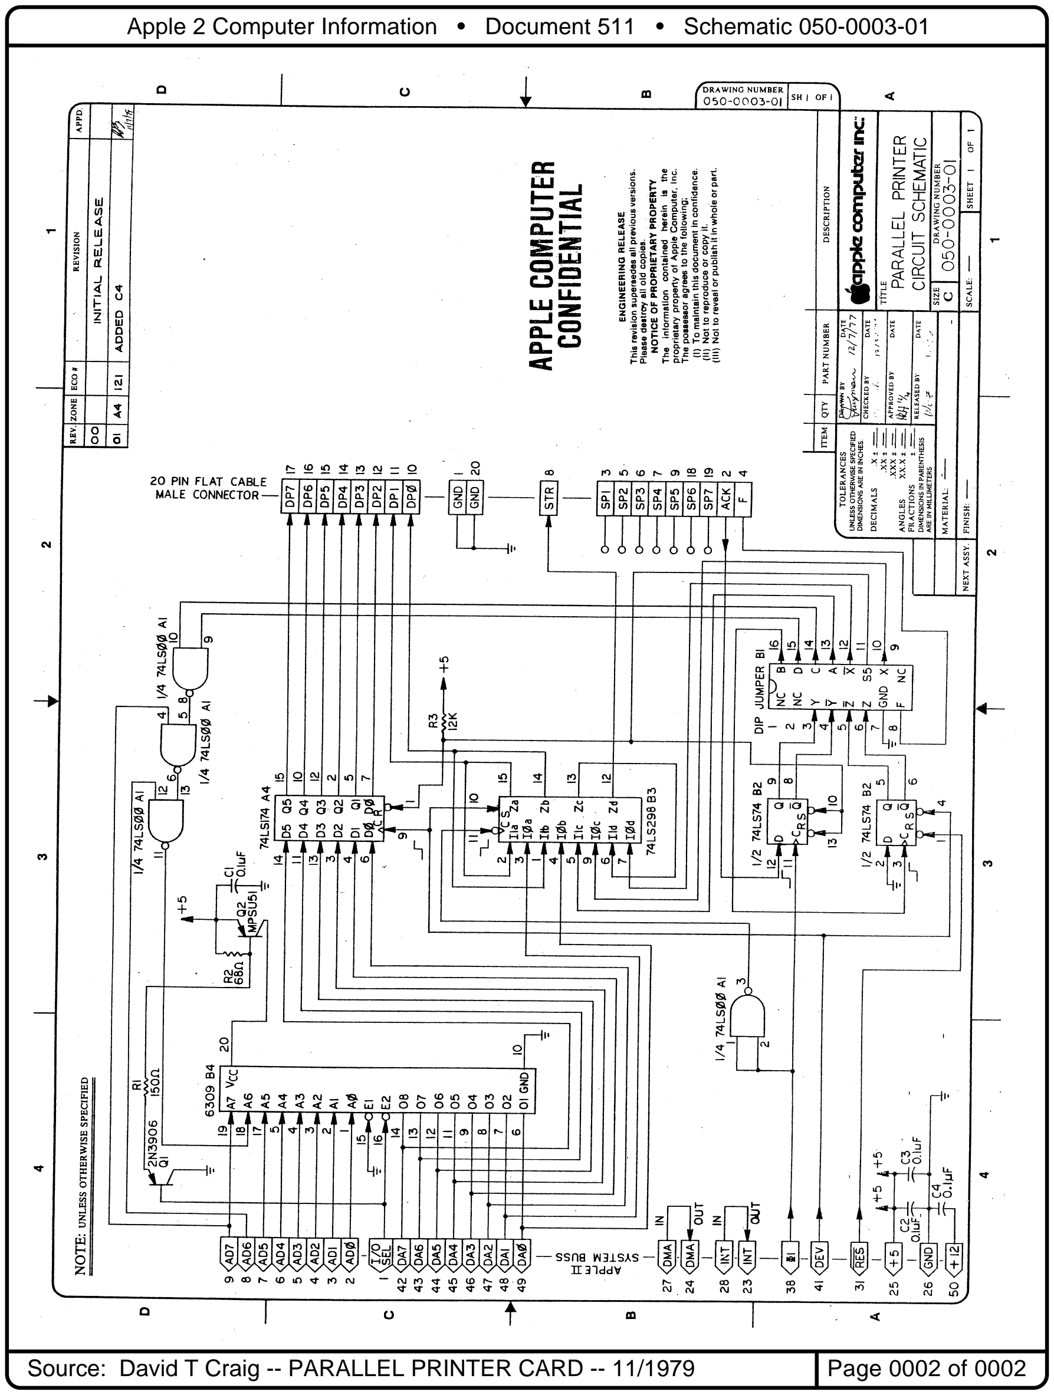
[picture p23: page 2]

Apple 2 Computer Information • Document 511 • Schematic 050-0003-01

Source: David T Craig -- PARALLEL PRINTER CARD -- 11/1979 | Page 0002 of 0002

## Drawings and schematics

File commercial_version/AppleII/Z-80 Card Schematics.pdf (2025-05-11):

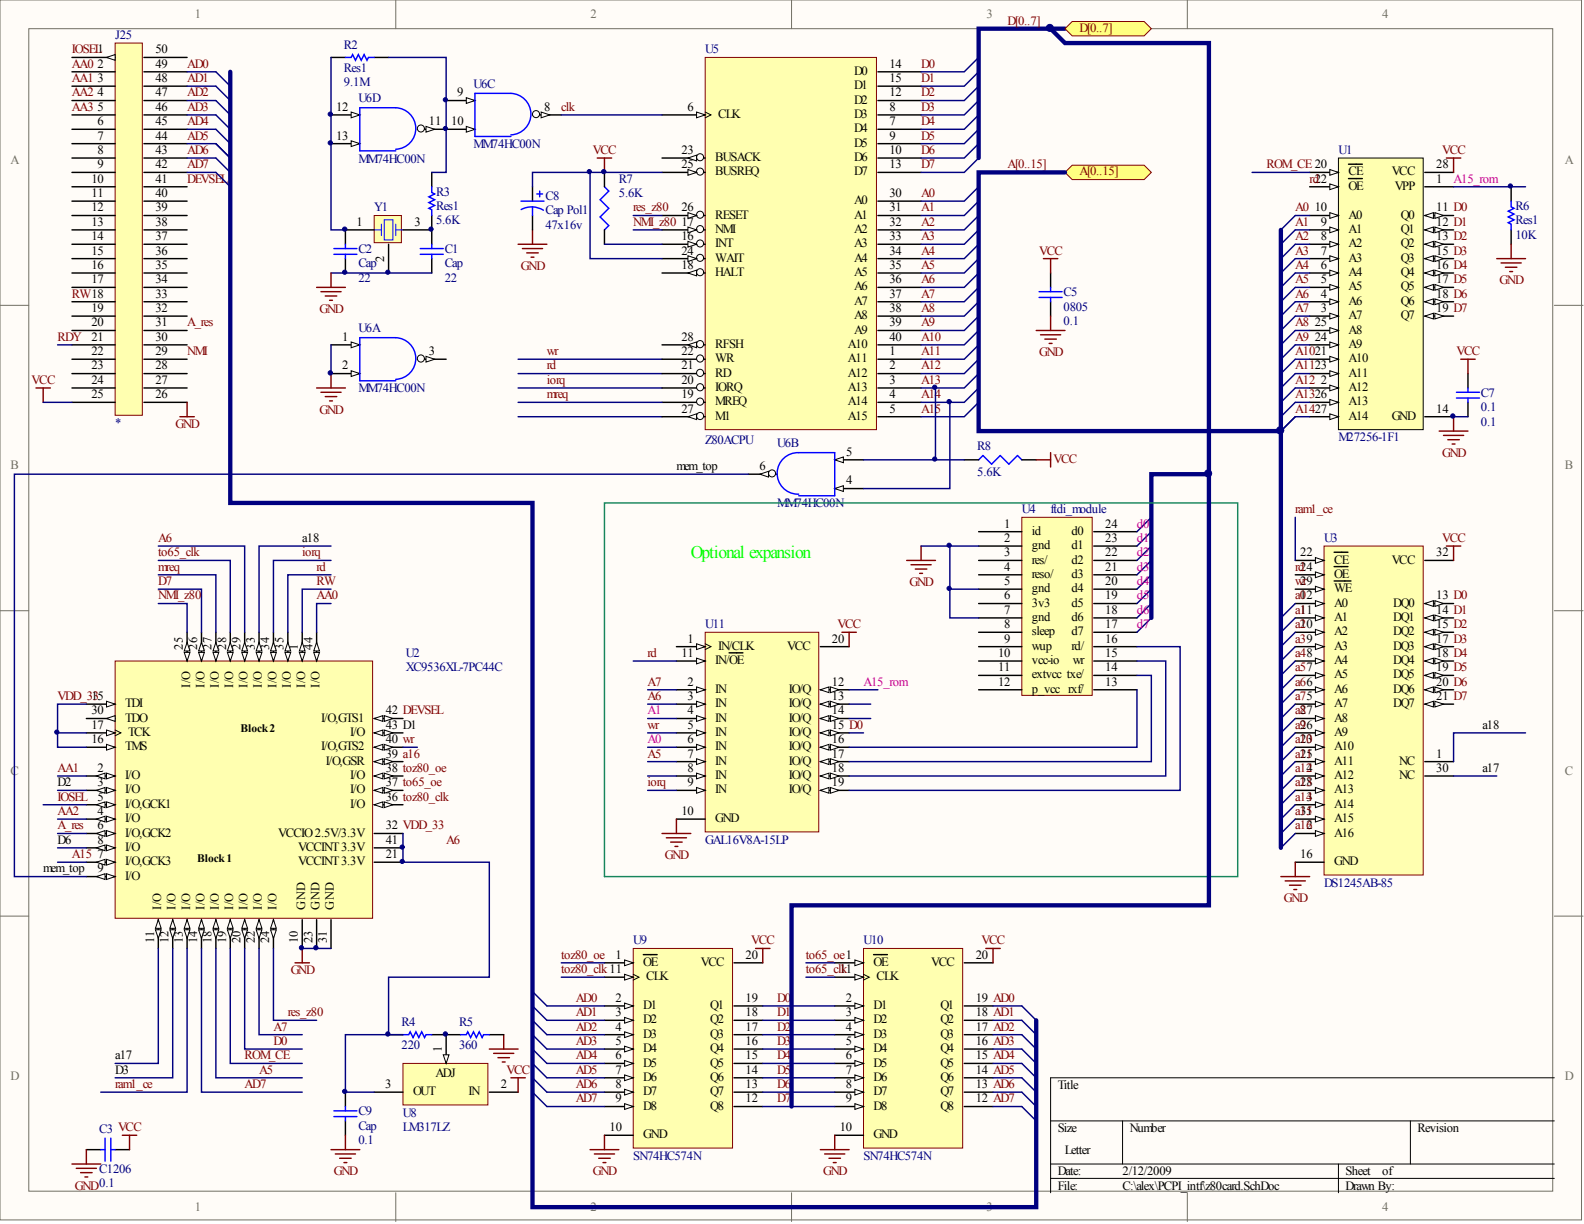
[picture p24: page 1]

GND 10

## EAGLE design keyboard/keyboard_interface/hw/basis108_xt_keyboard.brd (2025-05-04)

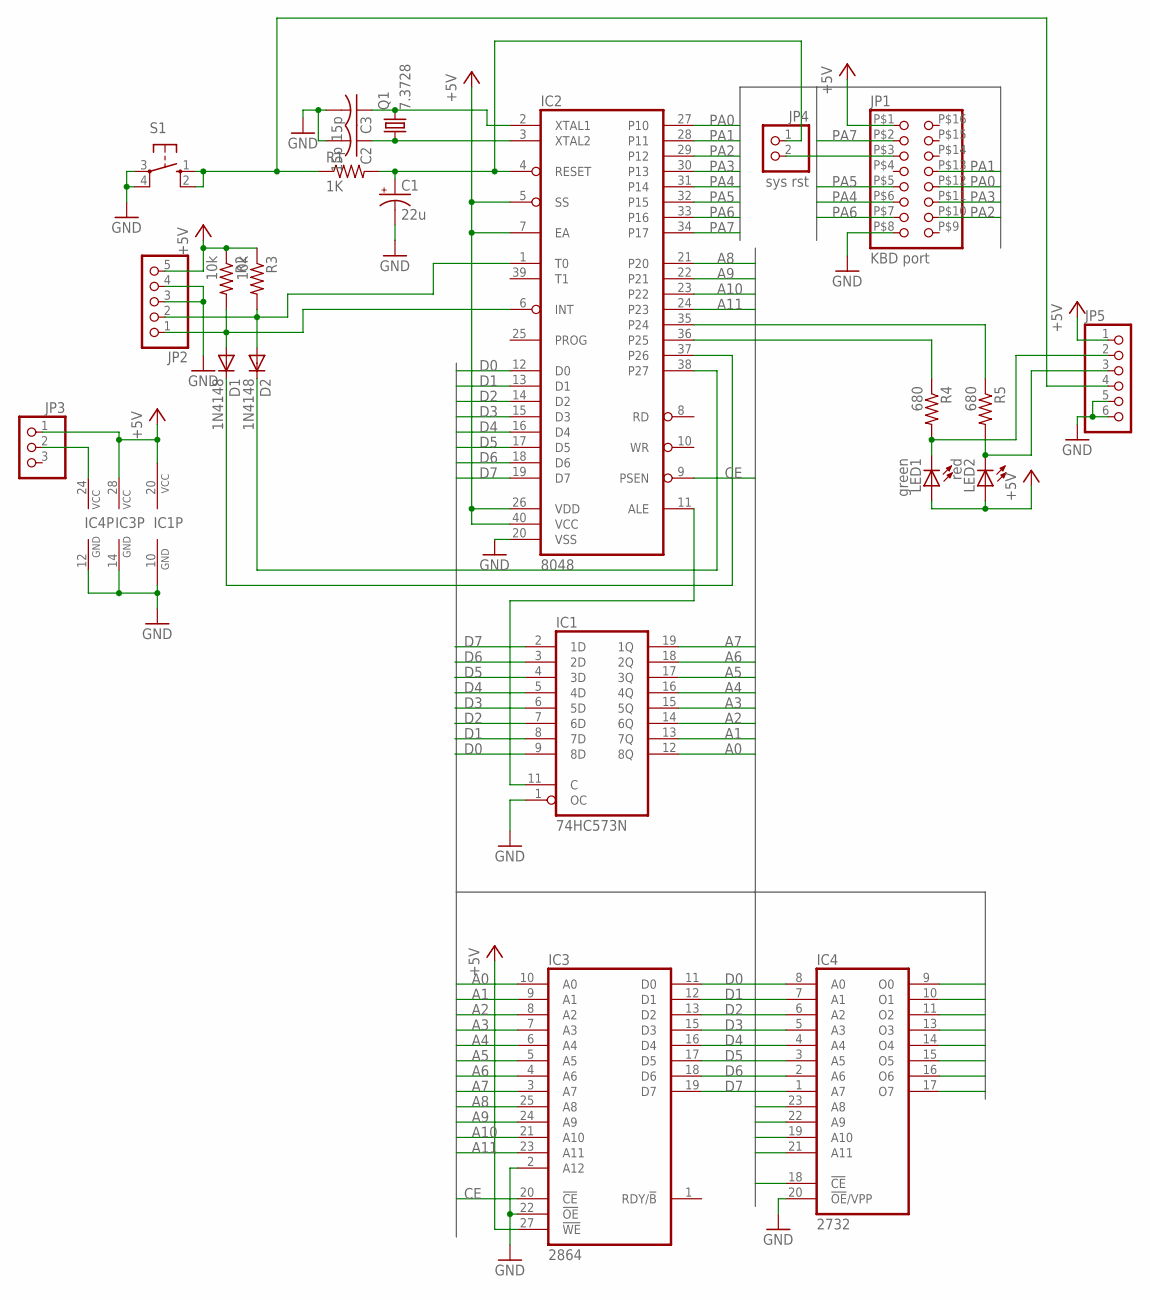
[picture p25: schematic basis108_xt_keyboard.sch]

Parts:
C1: 22u; E2,5-6
C2, C3: 15p; C025-040X050
D1, D2: 1N4148; DO35-7
IC1: 74HC573N; DIL20
IC2: 8048; DIL40
IC3: 2864; DIL28
IC4: 2732; DIL24
JP1: KBD port; 2X8DIL
JP2: PINHD-1X5; 1X05
JP3: PINHD-1X3; 1X03
JP4: sys rst; 1X02
JP5: PINHD-1X6; 1X06
LED1: green; LED3MM
LED2: red; LED3MM
Q1: 7.3728; HC49U-H
R1: 1K; 0204/7
R2, R3: 10k; 0204/7
R4, R5: 680; 0204/7
S1: 10-XX; B3F-10XX

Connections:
+5V: IC1.20 (VCC), IC2.5 (SS), IC2.7 (EA), IC2.26 (VDD), IC2.40 (VCC), IC3.27 (!WE), IC3.28 (VCC), JP1.P$1 (1), JP2.5, JP3.1, JP5.1, LED1.A, LED2.A, R2.1, R3.1
A0: IC1.12 (8Q), IC3.10 (A0), IC4.8 (A0)
A1: IC1.13 (7Q), IC3.9 (A1), IC4.7 (A1)
A2: IC1.14 (6Q), IC3.8 (A2), IC4.6 (A2)
A3: IC1.15 (5Q), IC3.7 (A3), IC4.5 (A3)
A4: IC1.16 (4Q), IC3.6 (A4), IC4.4 (A4)
A5: IC1.17 (3Q), IC3.5 (A5), IC4.3 (A5)
A6: IC1.18 (2Q), IC3.4 (A6), IC4.2 (A6)
A7: IC1.19 (1Q), IC3.3 (A7), IC4.1 (A7)
A8: IC2.21 (P20), IC3.25 (A8), IC4.23 (A8)
A9: IC2.22 (P21), IC3.24 (A9), IC4.22 (A9)
A10: IC2.23 (P22), IC3.21 (A10), IC4.19 (A10)
A11: IC2.24 (P23), IC3.23 (A11), IC4.21 (A11)
ALE: IC1.11 (C), IC2.11 (ALE)
CE: IC2.9 (PSEN), IC3.20 (!CE), IC4.18 (!CE)
D0: IC1.9 (8D), IC2.12 (D0), IC3.11 (D0), IC4.9 (O0)
D1: IC1.8 (7D), IC2.13 (D1), IC3.12 (D1), IC4.10 (O1)
D2: IC1.7 (6D), IC2.14 (D2), IC3.13 (D2), IC4.11 (O2)
D3: IC1.6 (5D), IC2.15 (D3), IC3.15 (D3), IC4.13 (O3)
D4: IC1.5 (4D), IC2.16 (D4), IC3.16 (D4), IC4.14 (O4)
D5: IC1.4 (3D), IC2.17 (D5), IC3.17 (D5), IC4.15 (O5)
D6: IC1.3 (2D), IC2.18 (D6), IC3.18 (D6), IC4.16 (O6)
D7: IC1.2 (1D), IC2.19 (D7), IC3.19 (D7), IC4.17 (O7)
GND: C1.-, C2.2, C3.2, IC1.1 (OC), IC1.10 (GND), IC2.20 (VSS), IC3.2 (A12), IC3.14 (GND), IC3.22 (!OE), IC4.12 (GND), IC4.20 (!OE!/VPP), JP1.P$8 (15), JP2.3, JP2.4, JP5.5, JP5.6, S1.3, S1.4 (P1)
unnamed: C2.1, IC2.3 (XTAL2), Q1.1
unnamed: C3.1, IC2.2 (XTAL1), Q1.2
unnamed: C1.+, IC2.4 (RESET), JP4.1, R1.2
unnamed: IC4.24 (VCC), JP3.2
unnamed: JP5.4, R1.1, S1.1 (S), S1.2 (S1)
unnamed: D1.A, IC2.6 (INT), JP2.1, R2.2
unnamed: D2.A, IC2.1 (T0), JP2.2, R3.2
unnamed: D2.C, IC2.38 (P27)
unnamed: D1.C, IC2.37 (P26)
unnamed: IC2.36 (P25), R4.1
unnamed: IC2.35 (P24), R5.1
unnamed: JP5.3, LED2.K (C), R5.2
unnamed: JP5.2, LED1.K (C), R4.2
unnamed: JP1.P$3 (5), JP4.2
PA0: IC2.27 (P10), JP1.P$12 (10)
PA1: IC2.28 (P11), JP1.P$13 (8)
PA2: IC2.29 (P12), JP1.P$10 (14)
PA3: IC2.30 (P13), JP1.P$11 (12)
PA4: IC2.31 (P14), JP1.P$6 (11)
PA5: IC2.32 (P15), JP1.P$5 (9)
PA6: IC2.33 (P16), JP1.P$7 (13)
PA7: IC2.34 (P17), JP1.P$2 (3)

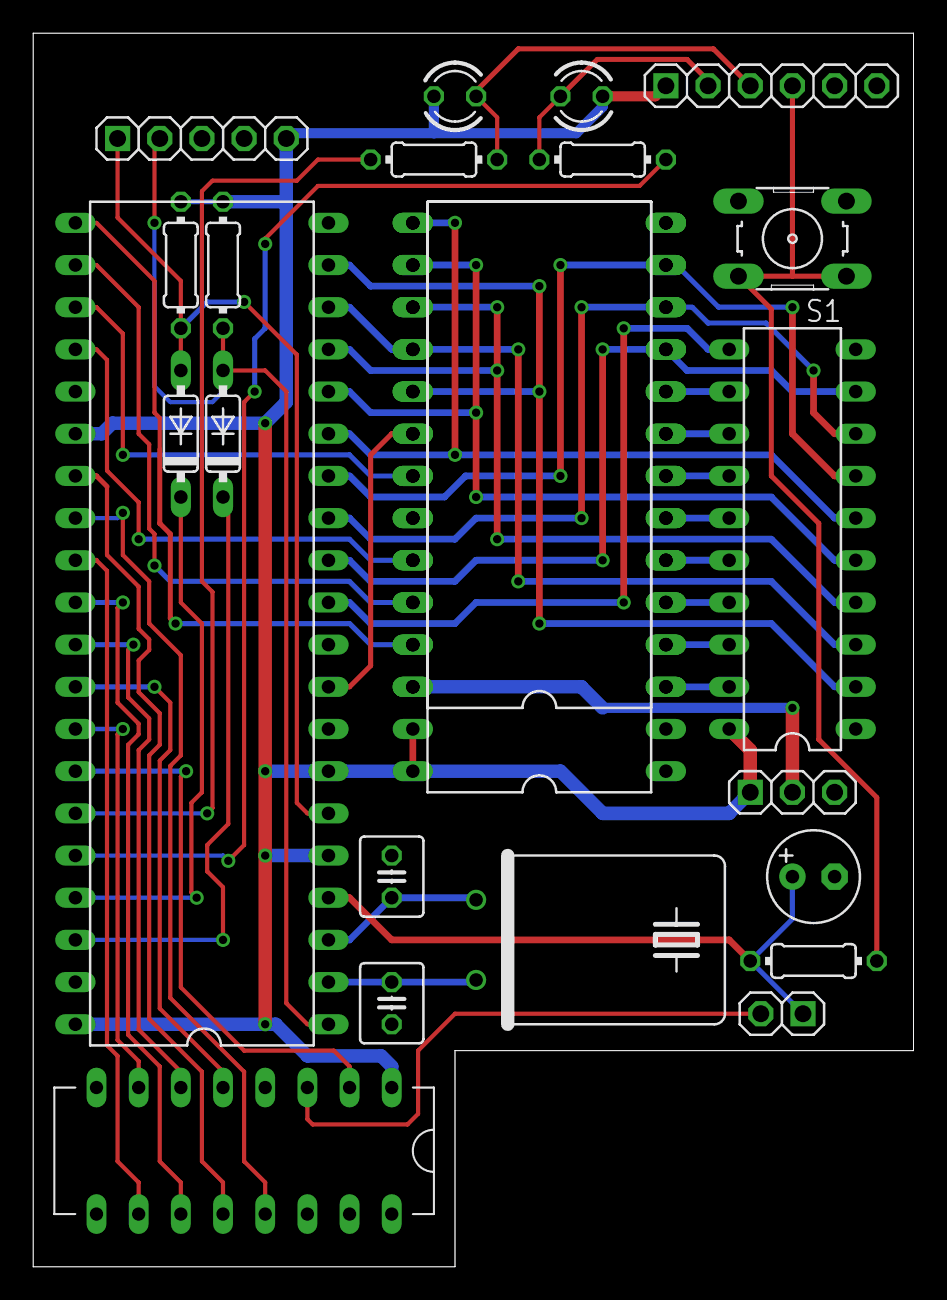
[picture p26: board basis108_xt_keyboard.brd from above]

Board: 2 copper layers, 53.0 x 74.3 mm, 23 parts (0 on the bottom side), 46 nets.

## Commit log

2025-05-11 Add information about floppy drive connection. Data signal timings
    [003_data_spacing_zeroed_image.CSV, 004_data_line_12.5Msps.CSV, 004_data_spacing_zeroed_image.CSV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]
2025-05-18 add images of main board
2025-05-18 main board schematic
